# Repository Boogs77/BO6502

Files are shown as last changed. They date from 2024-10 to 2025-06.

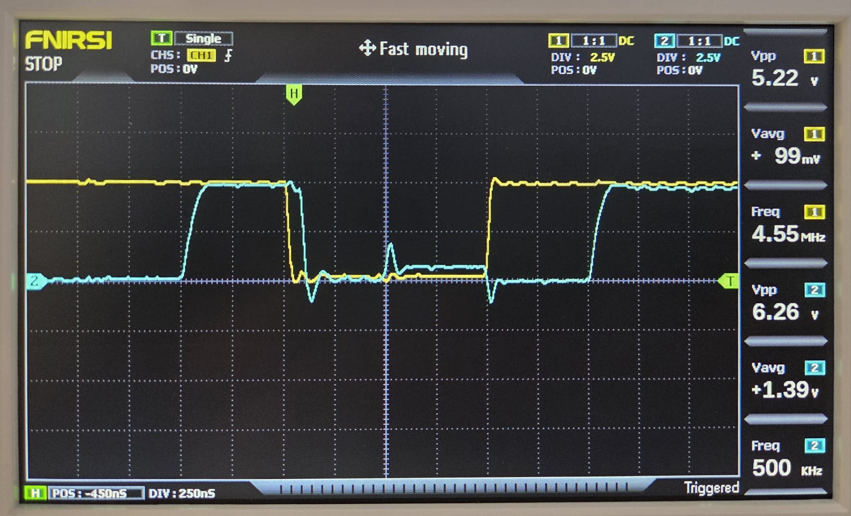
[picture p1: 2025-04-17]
BO6502 VDU/export/CSW-D7.jpg

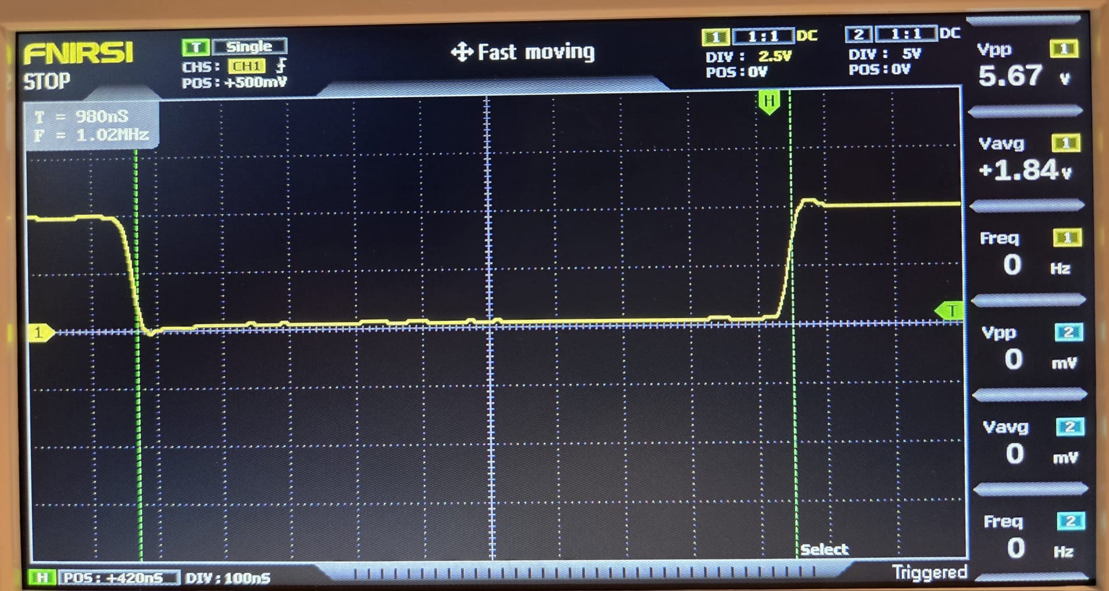
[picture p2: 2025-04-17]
BO6502 VDU/export/CSW.jpg

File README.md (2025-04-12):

**SPECIFICATION**

MICROPROCESSOR The Western Design Center Inc. W65C02S

Clock frequency 1.0 MHz

Optional Clock frequency 2.0 MHz e 500 KHz

ROM Memory ATMEL AT28C256

On-board ROM capacitor 32 Kbyte

RAM Memory HITACHI HM62256lp-12

On-board RAM capacitor 32 Kbyte

VIDEO OUTPUT LCD Display 16x2

Internal Chip HITACHI HD44780U

SERIAL COMMUNICATION Through serial port DB9

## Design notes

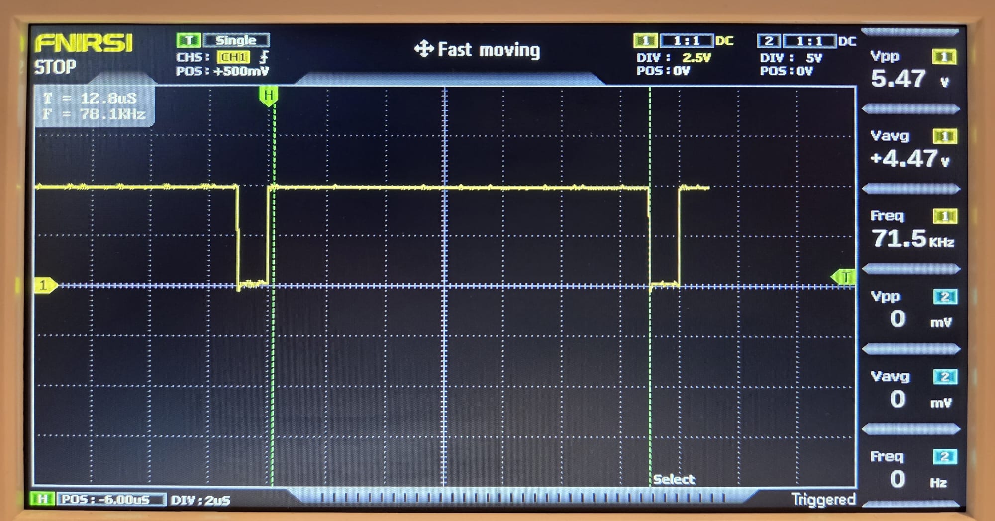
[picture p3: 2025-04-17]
BO6502 VDU/export/CSW-IN-LOOP.jpg

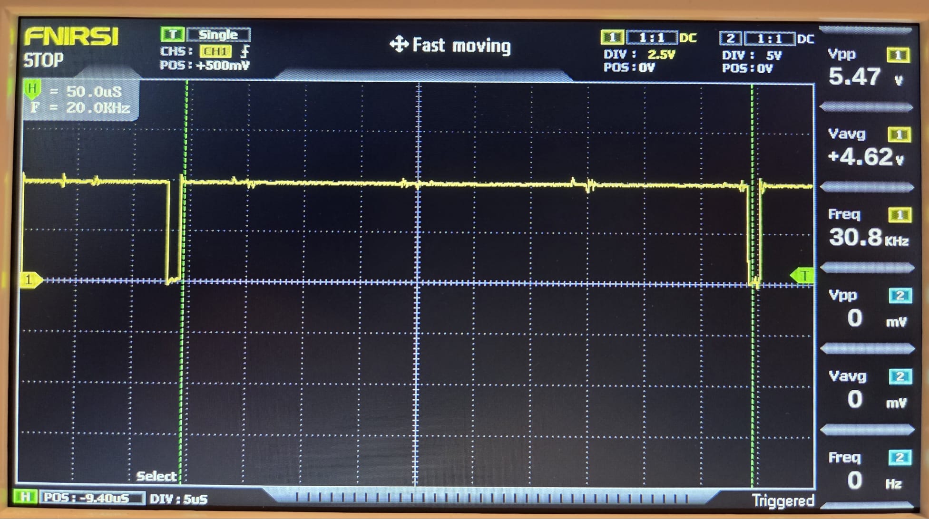
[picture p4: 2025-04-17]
BO6502 VDU/export/CSW-LOOP.jpg

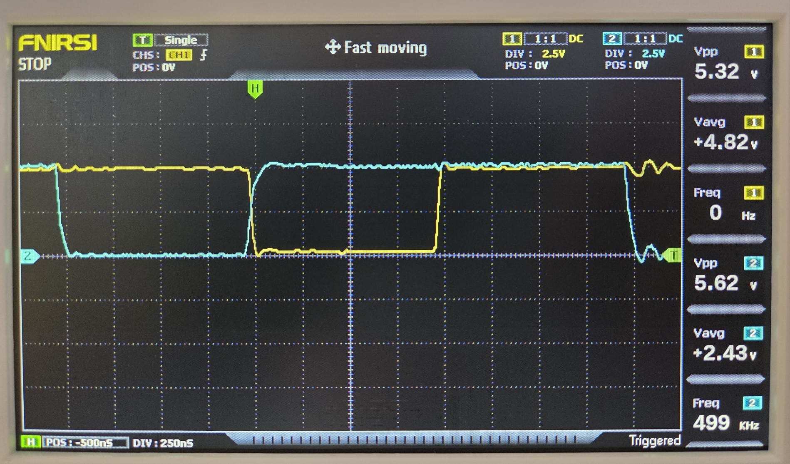
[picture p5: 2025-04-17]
BO6502 VDU/export/CSW-A0.jpg

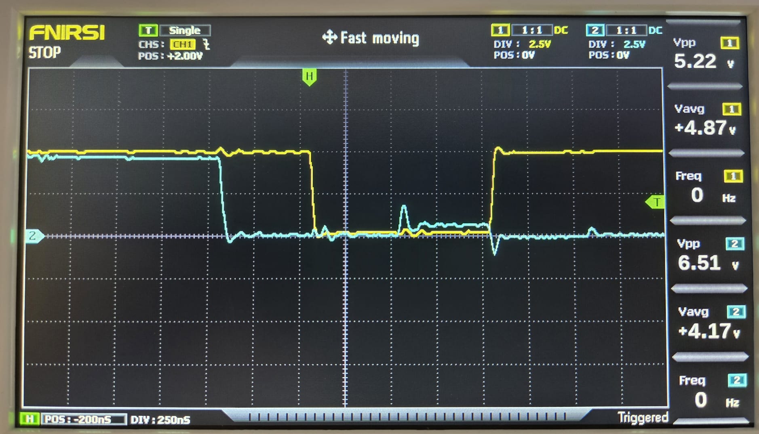
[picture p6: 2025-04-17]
BO6502 VDU/export/CSW-LSB.jpg

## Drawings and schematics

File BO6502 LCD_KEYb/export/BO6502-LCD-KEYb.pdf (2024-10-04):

A

A

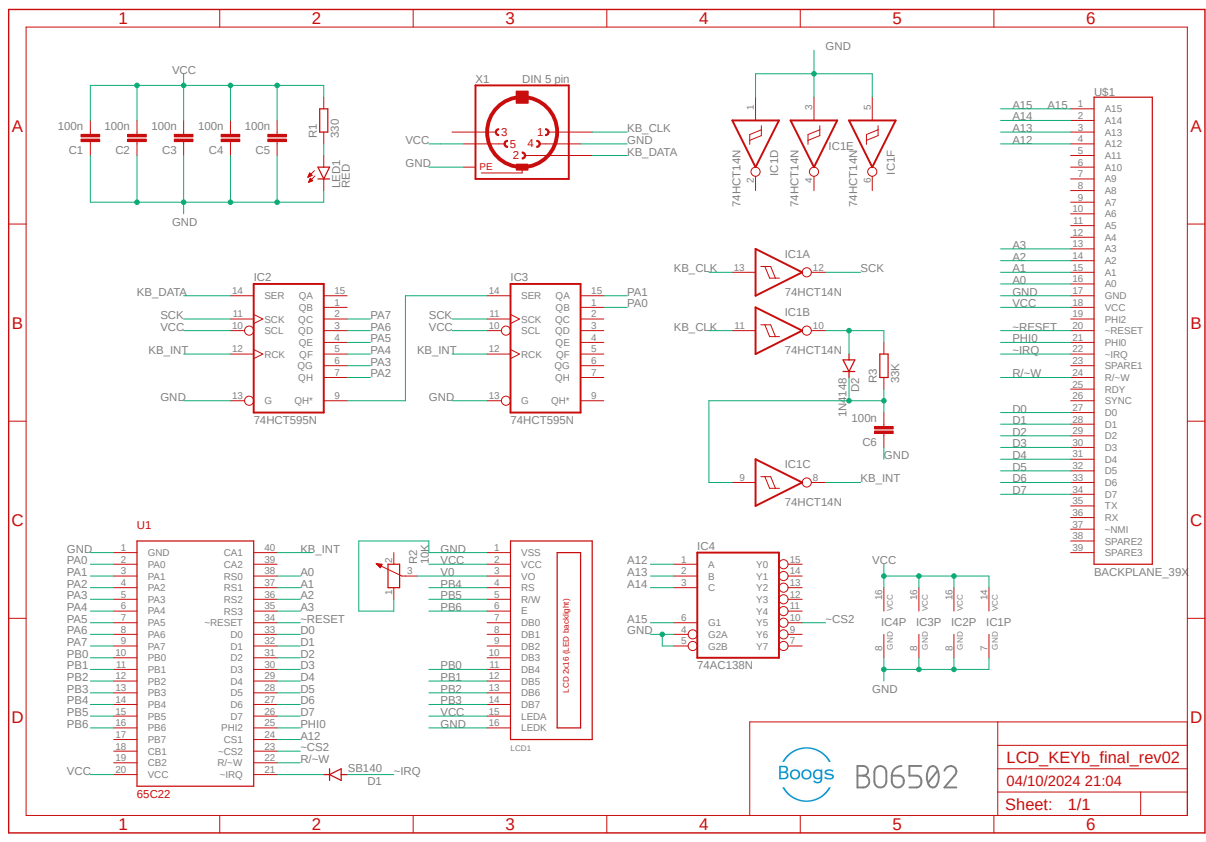
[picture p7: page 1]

GND

PB3 13 | | DB6 13
PB4 14 | DB7 14
PB5 15 | VCC | LEDA 15
PB6 16 | GND | LEDK 16

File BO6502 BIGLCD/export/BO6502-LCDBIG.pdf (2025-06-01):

Sheet: ABCD | 1 | 2 | 3 | 4 | 5 | 6 | ABCD 1 | 2 | 3 | 4 | 5 | 6

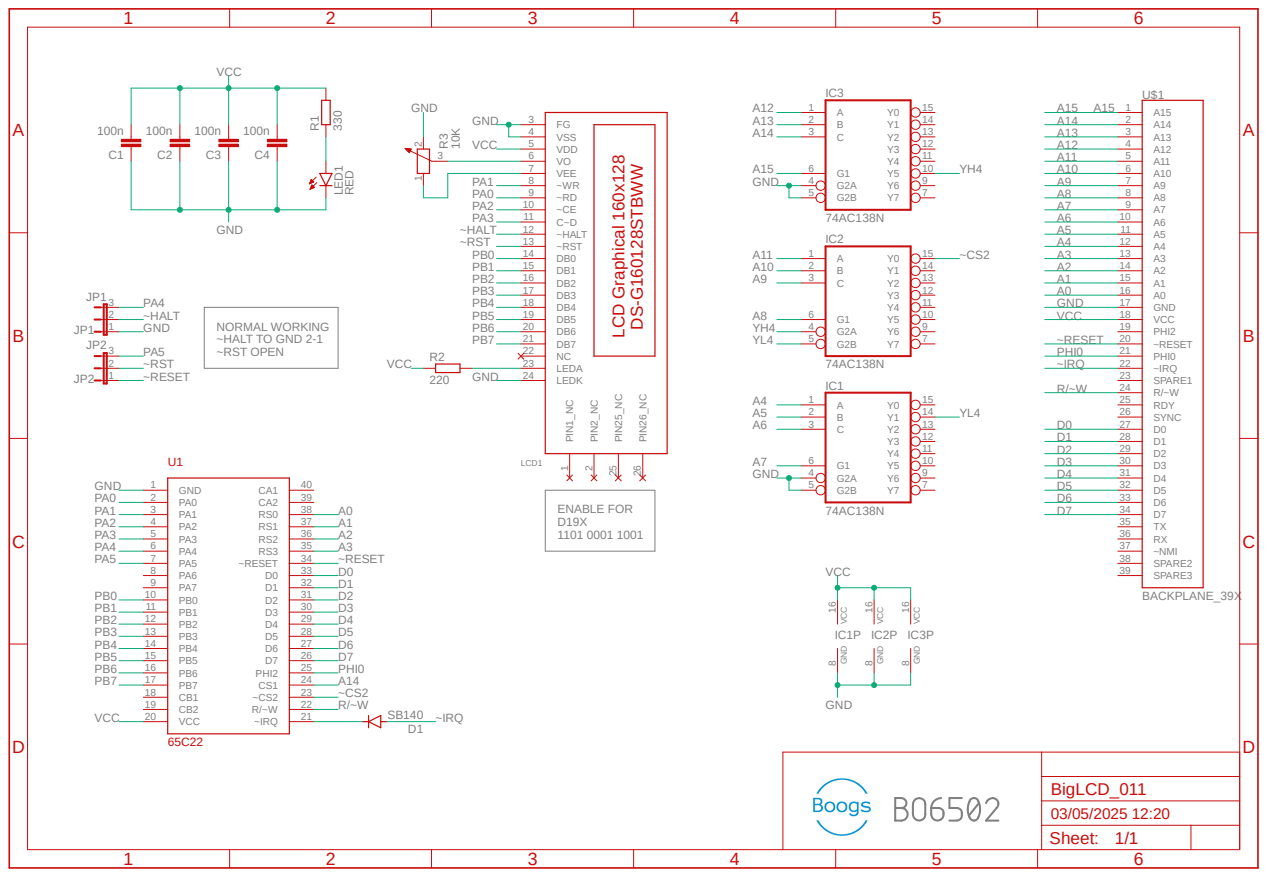
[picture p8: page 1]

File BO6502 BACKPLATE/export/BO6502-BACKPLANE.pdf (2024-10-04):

A

A

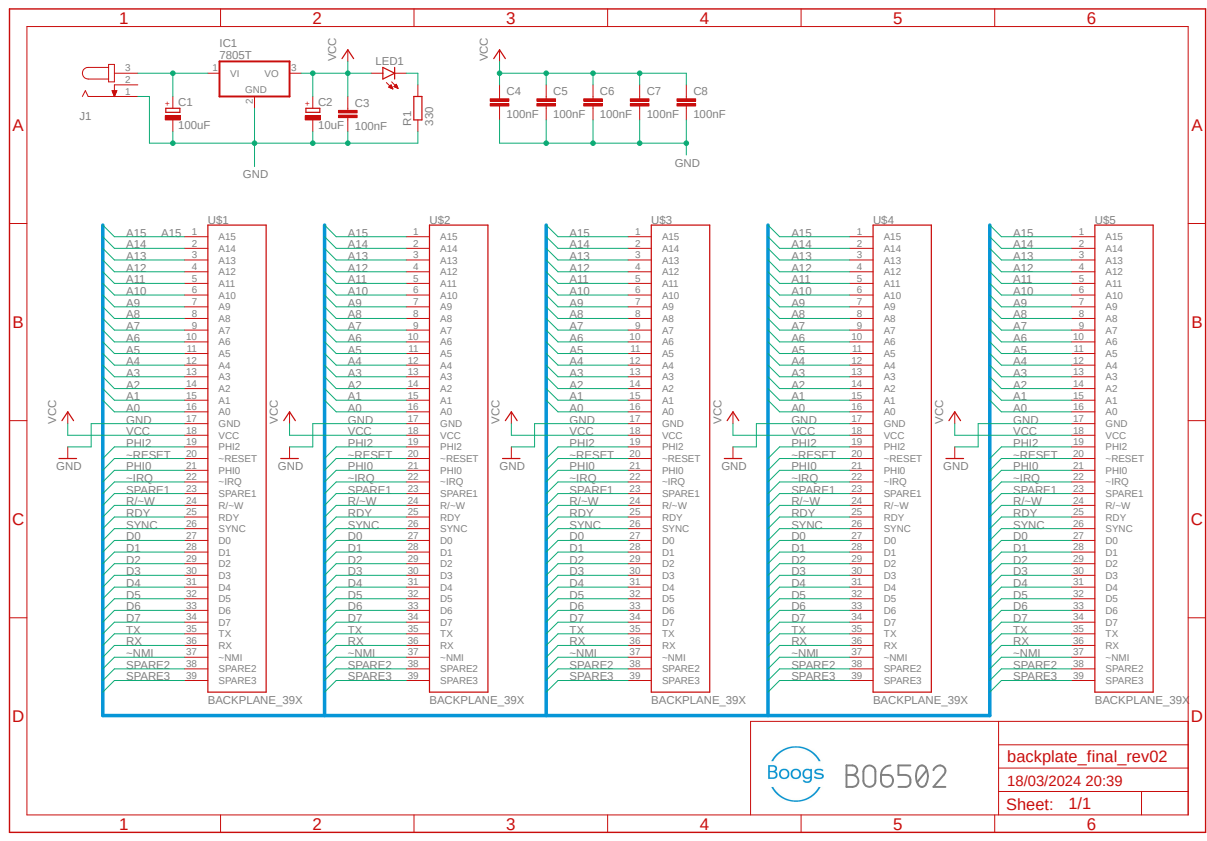
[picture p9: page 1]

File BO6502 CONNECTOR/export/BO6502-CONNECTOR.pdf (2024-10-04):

Sheet: ABCD | 1 | 2 | 3 | 4 | 5 | 6 | ABCD 1 | 2 | 3 | 4 | 5 | 6

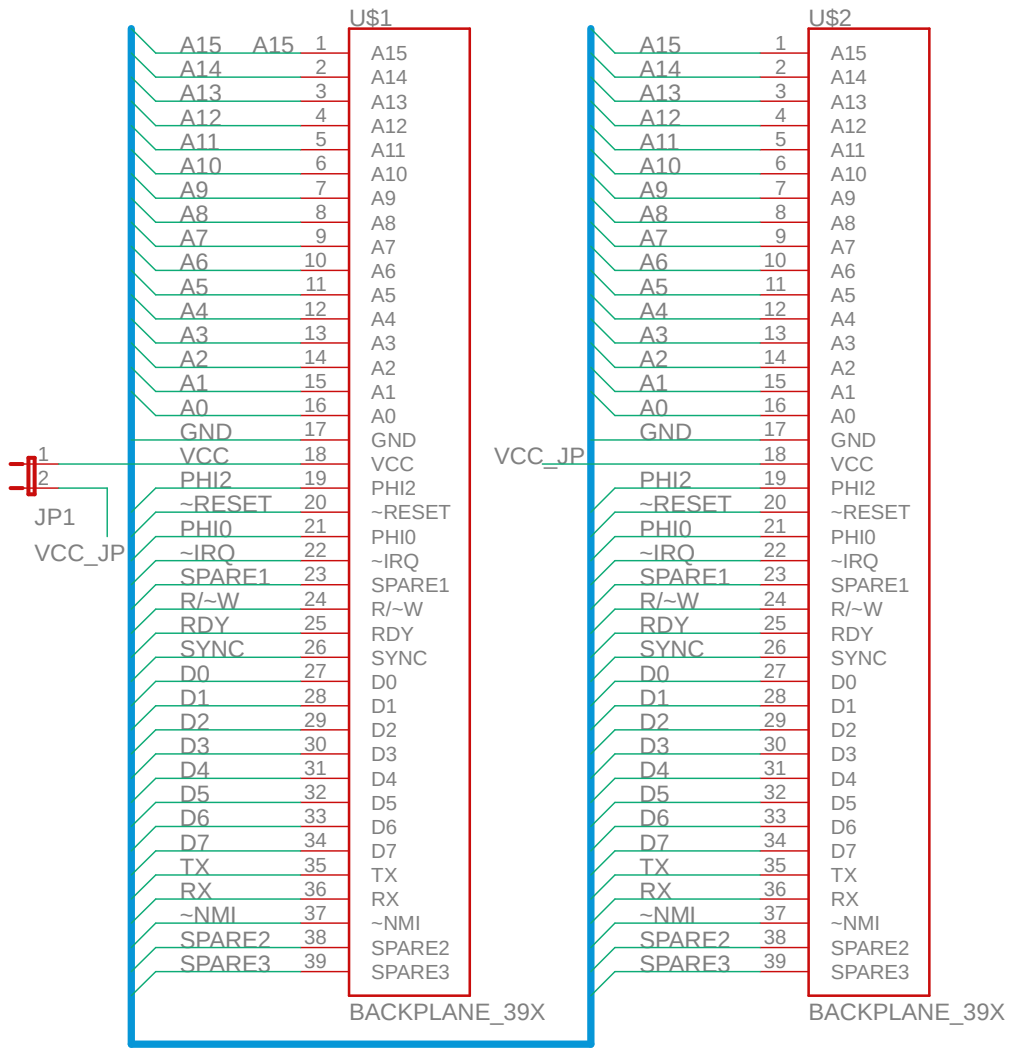
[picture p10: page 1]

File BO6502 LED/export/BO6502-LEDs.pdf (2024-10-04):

Y7 | 7 Y6 | 9 Y5 | 10 Y4 | 11 Y3 | 12 Y2 | 13 Y1 | 14 Y0 | 15
A

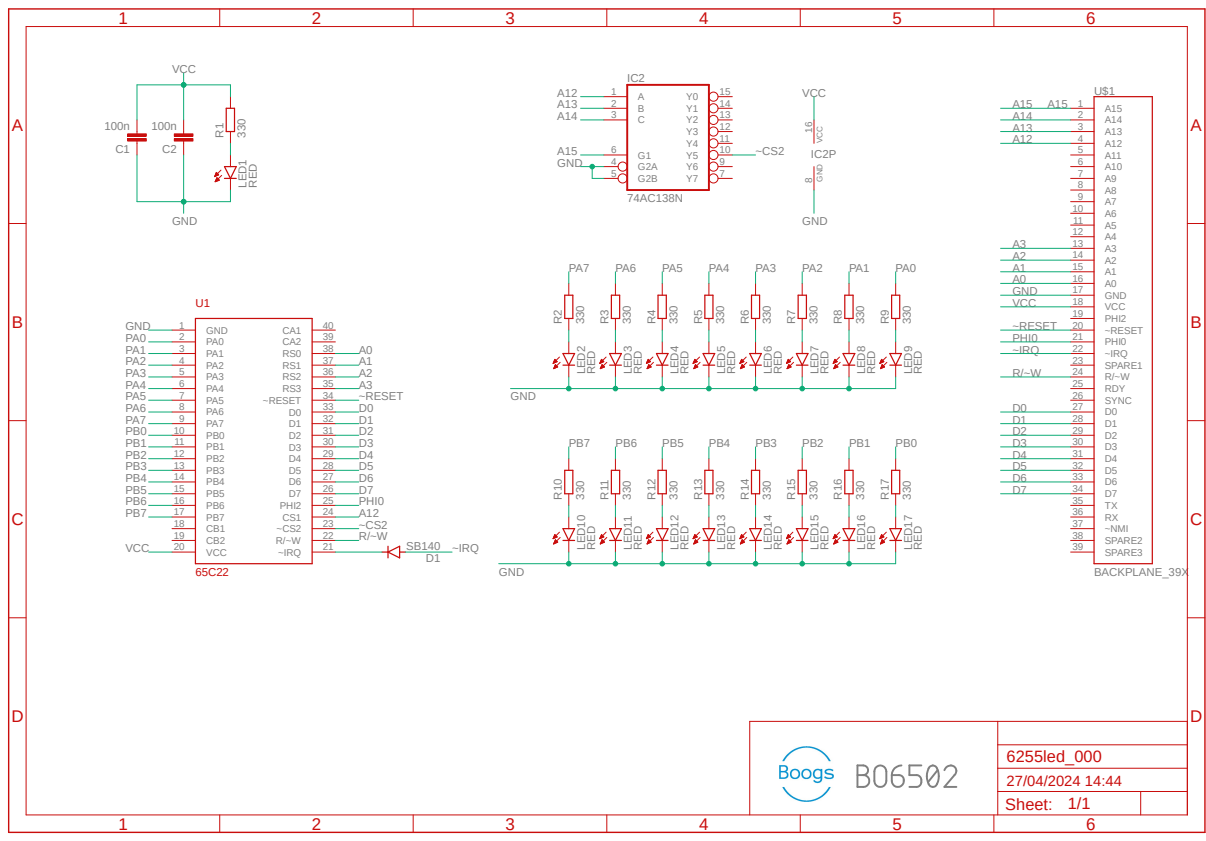
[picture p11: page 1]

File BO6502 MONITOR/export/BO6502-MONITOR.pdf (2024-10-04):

Sheet: ABCD | 1 | 2 | 3 | 4 | 5 | 6 | ABCD 1 | 2 | 3 | 4 | 5 | 6

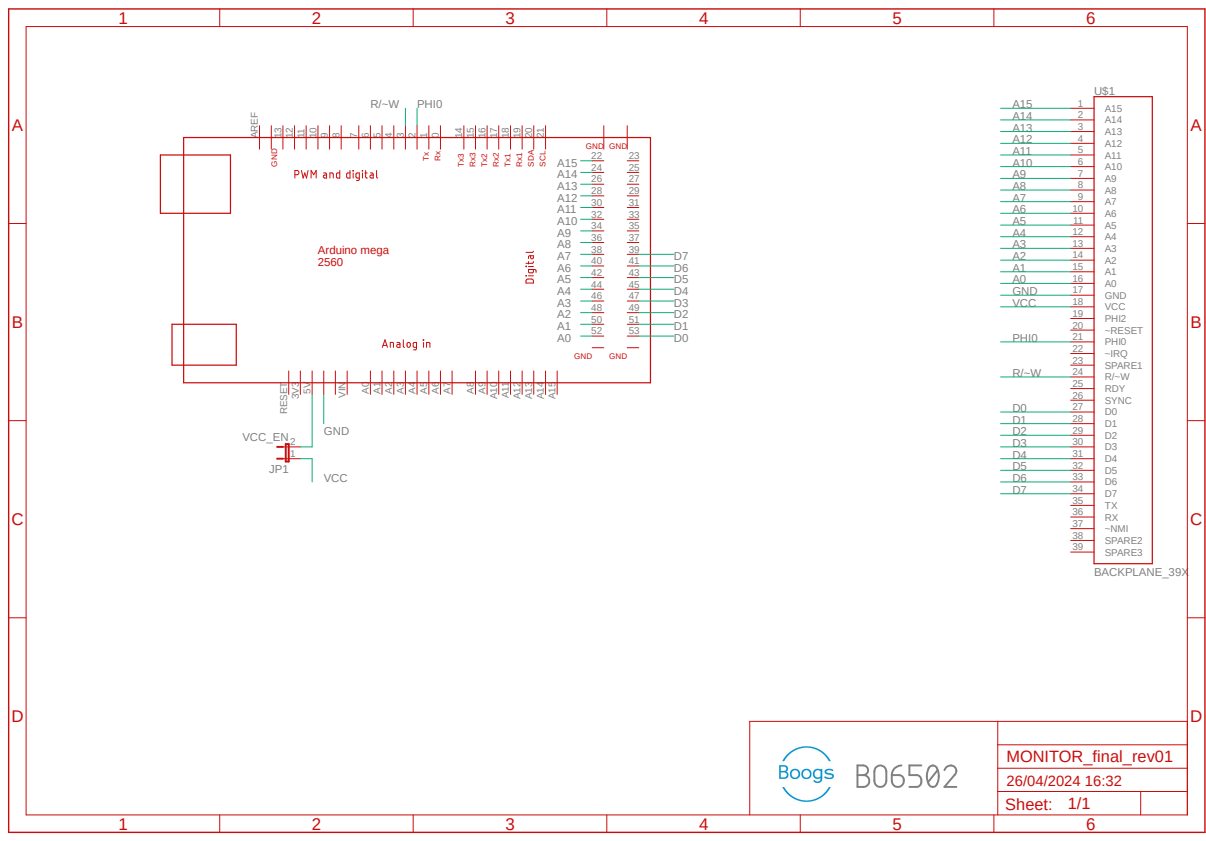
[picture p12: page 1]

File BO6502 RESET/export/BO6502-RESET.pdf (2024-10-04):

A

A

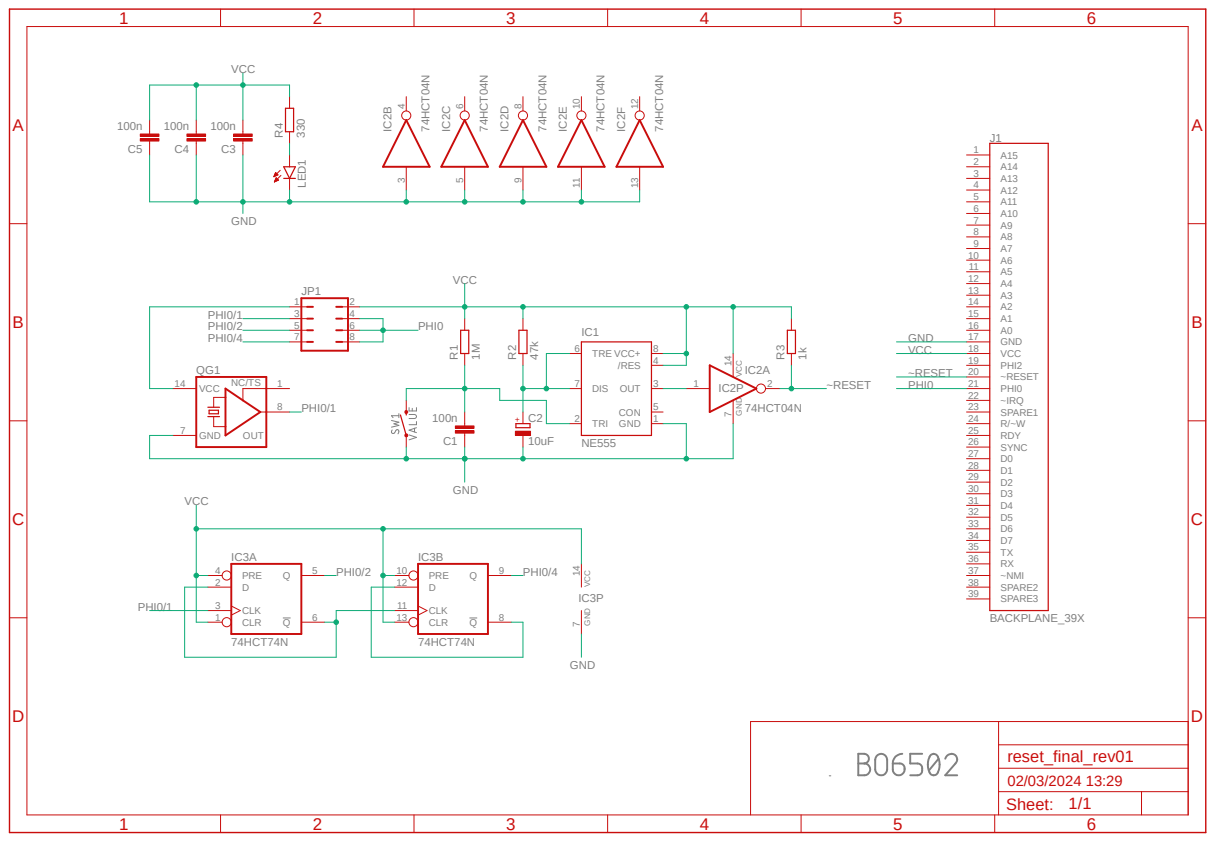
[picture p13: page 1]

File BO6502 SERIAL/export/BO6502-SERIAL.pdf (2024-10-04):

Sheet: ABCD | 1 | 2 | 3 | 4 | 5 | 6 | ABCD 1 | 2 | 3 | 4 | 5 | 6

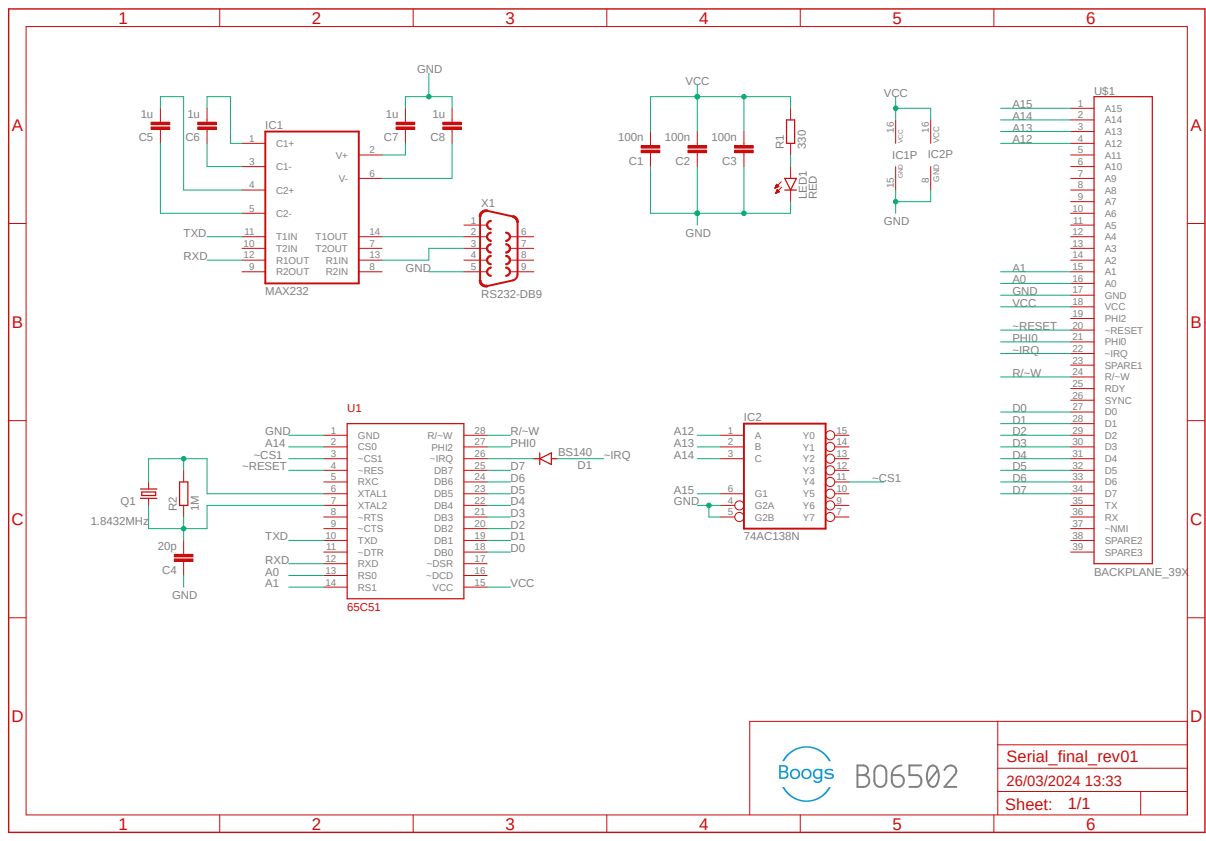
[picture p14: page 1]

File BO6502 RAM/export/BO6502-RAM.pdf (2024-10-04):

A

A

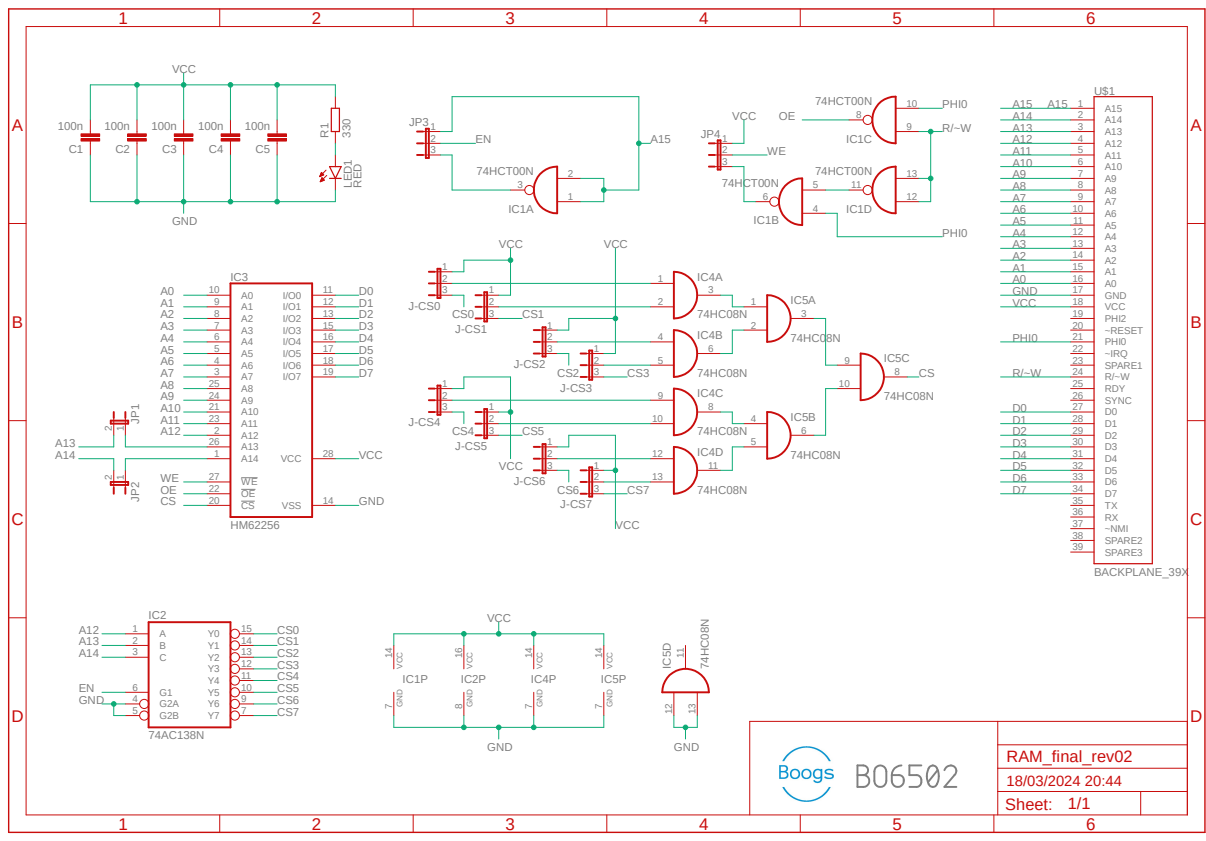
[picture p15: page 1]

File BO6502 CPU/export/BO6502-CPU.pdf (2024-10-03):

A

A

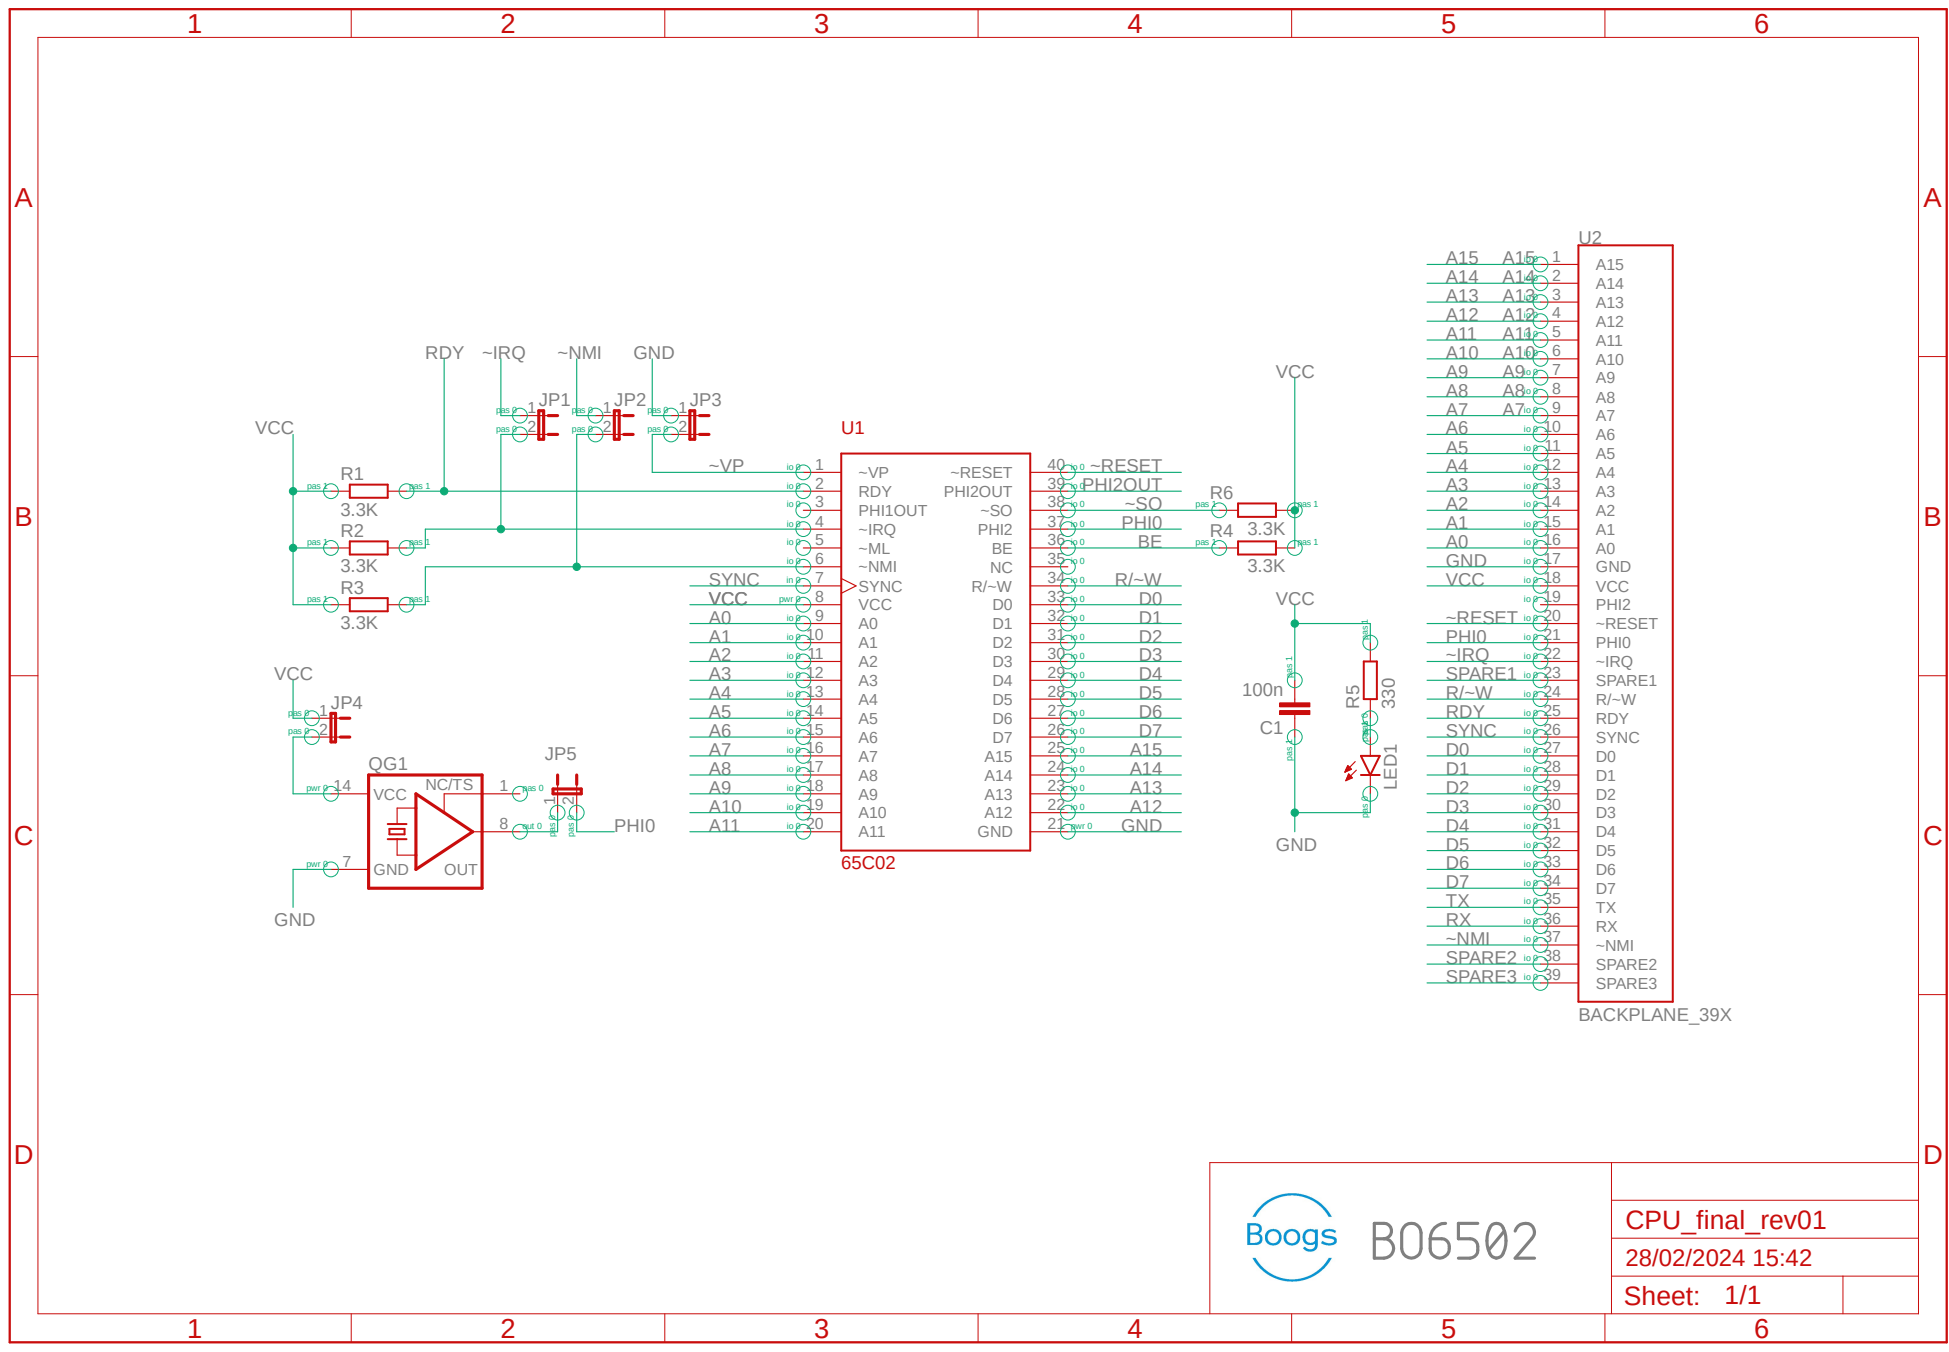
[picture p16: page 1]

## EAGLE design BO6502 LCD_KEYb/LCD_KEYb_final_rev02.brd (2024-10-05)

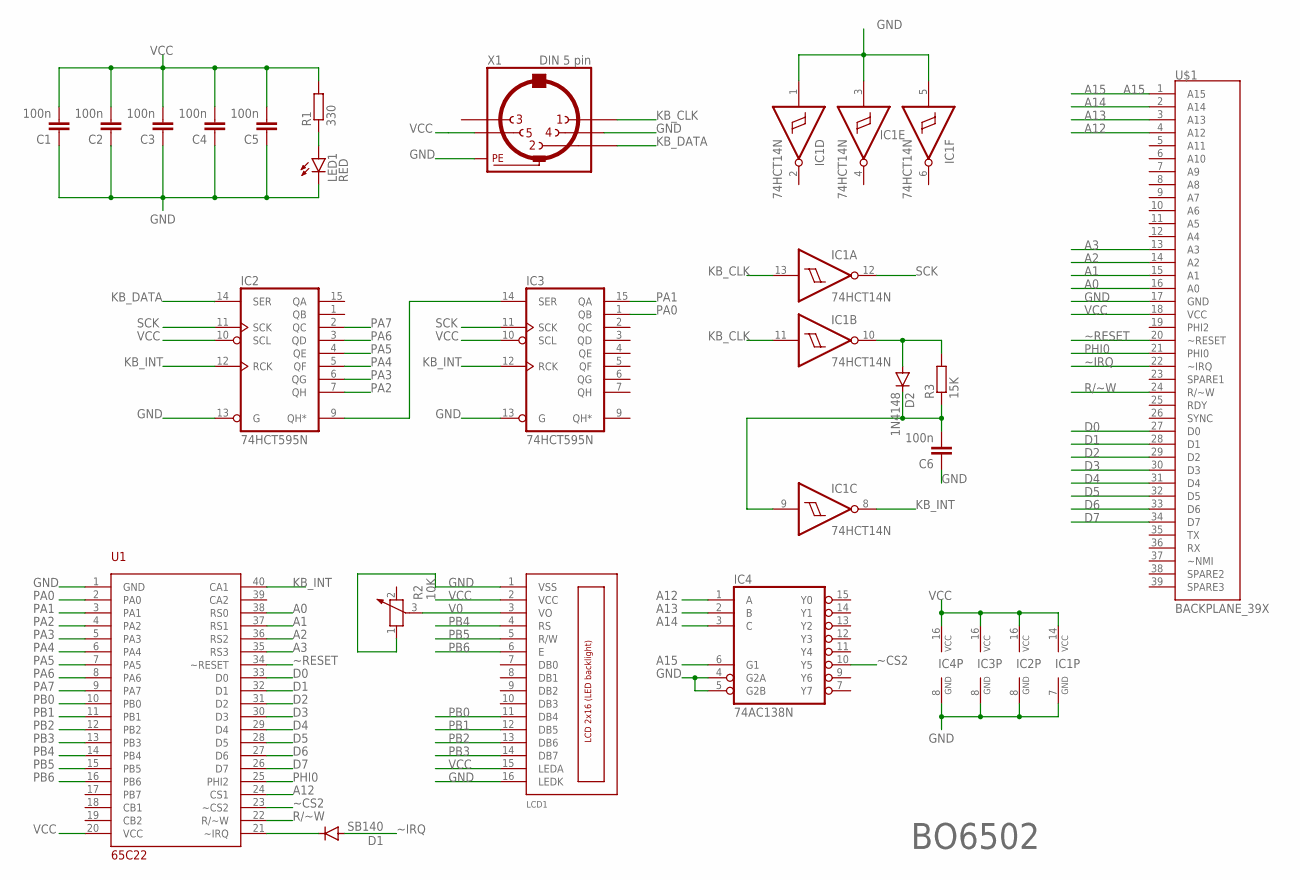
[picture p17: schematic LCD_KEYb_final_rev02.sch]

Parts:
C1, C2, C3, C4, C5, C6: 100n; C025-025X050
D1: SB140; DO41-10
D2: 1N4148; DO35-7
IC1: 74HCT14N; DIL14
IC2, IC3: 74HCT595N; DIL16
IC4: 74AC138N; DIL16
LCD1: LCD_2X16_SIL; HY-1602F
LED1: RED; LED5MM
R1: 330; 0207/10
R2: 10K; PT-10
R3: 15K; 0207/10
U1: 65C22; DIL40
U$1: BACKPLANE_39X; BP_39X
X1: DIN 5 pin; MAB5SH

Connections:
A0: U1.38 (RS0), U$1.16 (A0)
A1: U1.37 (RS1), U$1.15 (A1)
A2: U1.36 (RS2), U$1.14 (A2)
A3: U1.35 (RS3), U$1.13 (A3)
A12: IC4.1 (A), U1.24 (CS1), U$1.4 (A12)
A13: IC4.2 (B), U$1.3 (A13)
A14: IC4.3 (C), U$1.2 (A14)
A15: IC4.6 (G1), U$1.1 (A15)
D0: U1.33 (D0), U$1.27 (D0)
D1: U1.32 (D1), U$1.28 (D1)
D2: U1.31 (D2), U$1.29 (D2)
D3: U1.30 (D3), U$1.30 (D3)
D4: U1.29 (D4), U$1.31 (D4)
D5: U1.28 (D5), U$1.32 (D5)
D6: U1.27 (D6), U$1.33 (D6)
D7: U1.26 (D7), U$1.34 (D7)
GND: C1.1, C2.1, C3.1, C4.1, C5.1, C6.1, IC1.1 (I), IC1.3 (I), IC1.5 (I), IC1.7 (GND), IC2.8 (GND), IC2.13 (G), IC3.8 (GND), IC3.13 (G), IC4.4 (G2A), IC4.5 (G2B), IC4.8 (GND), LCD1.1 (VSS), LCD1.16 (LEDK), LED1.K (C), R2.1, U1.1 (GND), U$1.17 (GND), X1.4, X1.PE, X1.PE@ (PE)
KB_CLK: IC1.11 (I), IC1.13 (I), X1.1
KB_DATA: IC2.14 (SER), X1.2
KB_INT: IC1.8 (O), IC2.12 (RCK), IC3.12 (RCK), U1.40 (CA1)
unnamed: D1.C, U1.21 (~IRQ)
unnamed: IC2.9 (QH*), IC3.14 (SER)
unnamed: D2.A, IC1.10 (O), R3.2
unnamed: C6.2, D2.C, IC1.9 (I), R3.1
unnamed: LED1.A, R1.1
PA0: IC3.1 (QB), U1.2 (PA0)
PA1: IC3.15 (QA), U1.3 (PA1)
PA2: IC2.7 (QH), U1.4 (PA2)
PA3: IC2.6 (QG), U1.5 (PA3)
PA4: IC2.5 (QF), U1.6 (PA4)
PA5: IC2.4 (QE), U1.7 (PA5)
PA6: IC2.3 (QD), U1.8 (PA6)
PA7: IC2.2 (QC), U1.9 (PA7)
PB0: LCD1.11 (DB4), U1.10 (PB0)
PB1: LCD1.12 (DB5), U1.11 (PB1)
PB2: LCD1.13 (DB6), U1.12 (PB2)
PB3: LCD1.14 (DB7), U1.13 (PB3)
PB4: LCD1.4 (RS), U1.14 (PB4)
PB5: LCD1.5 (R/W), U1.15 (PB5)
PB6: LCD1.6 (E), U1.16 (PB6)
PHI0: U1.25 (PHI2), U$1.21 (PHI0)
R/~W: U1.22 (R/~W), U$1.24 (R/~W)
SCK: IC1.12 (O), IC2.11 (SCK), IC3.11 (SCK)
V0: LCD1.3 (VO), R2.3
VCC: C1.2, C2.2, C3.2, C4.2, C5.2, IC1.14 (VCC), IC2.10 (SCL), IC2.16 (VCC), IC3.10 (SCL), IC3.16 (VCC), IC4.16 (VCC), LCD1.2 (VCC), LCD1.15 (LEDA), R1.2, U1.20 (VCC), U$1.18 (VCC), X1.5
~CS2: IC4.10 (Y5), U1.23 (~CS2)
~IRQ: D1.A, U$1.22 (~IRQ)
~RESET: U1.34 (~RESET), U$1.20 (~RESET)

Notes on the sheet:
BO6502

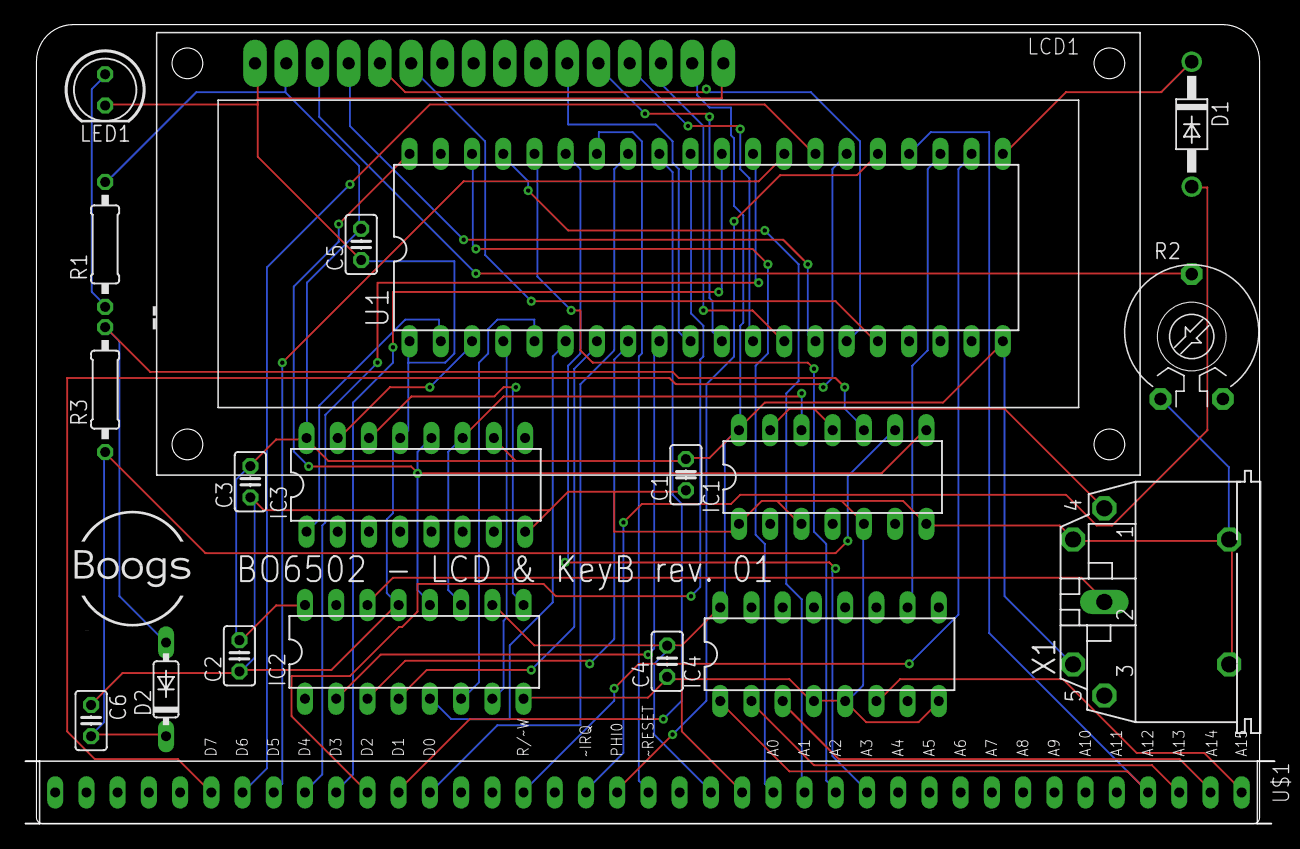
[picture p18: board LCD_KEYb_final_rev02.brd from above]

Board: 2 copper layers, 101.6 x 65.0 mm, 20 parts (0 on the bottom side), 48 nets.

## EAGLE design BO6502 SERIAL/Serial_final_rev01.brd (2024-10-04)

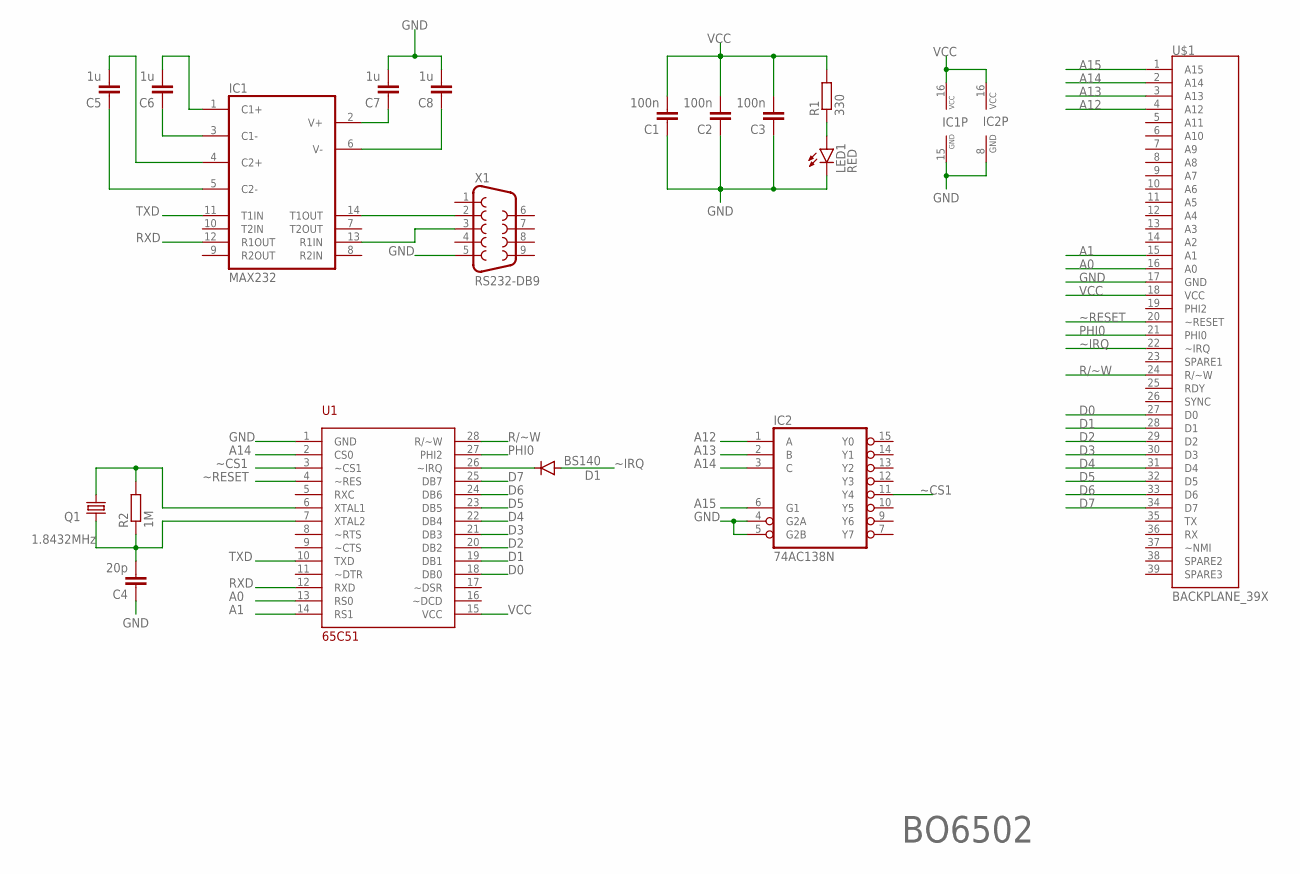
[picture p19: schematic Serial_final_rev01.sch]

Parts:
C1, C2, C3: 100n; C025-025X050
C4: 20p; C025-025X050
C5, C6, C7, C8: 1u; C050-025X075
D1: BS140; DO41-10
IC1: MAX232; DIL16
IC2: 74AC138N; DIL16
LED1: RED; LED5MM
Q1: 1.8432MHz; HC49/S
R1: 330; 0207/10
R2: 1M; 0207/10
U1: 65C51; DIL28
U$1: BACKPLANE_39X; BP_39X
X1: RS232-DB9; F09HP

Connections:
A0: U1.13 (RS0), U$1.16 (A0)
A1: U1.14 (RS1), U$1.15 (A1)
A12: IC2.1 (A), U$1.4 (A12)
A13: IC2.2 (B), U$1.3 (A13)
A14: IC2.3 (C), U1.2 (CS0), U$1.2 (A14)
A15: IC2.6 (G1), U$1.1 (A15)
D0: U1.18 (DB0), U$1.27 (D0)
D1: U1.19 (DB1), U$1.28 (D1)
D2: U1.20 (DB2), U$1.29 (D2)
D3: U1.21 (DB3), U$1.30 (D3)
D4: U1.22 (DB4), U$1.31 (D4)
D5: U1.23 (DB5), U$1.32 (D5)
D6: U1.24 (DB6), U$1.33 (D6)
D7: U1.25 (DB7), U$1.34 (D7)
GND: C1.1, C2.1, C3.1, C4.1, C7.2, C8.2, IC1.15 (GND), IC2.4 (G2A), IC2.5 (G2B), IC2.8 (GND), LED1.K (C), U1.1 (GND), U$1.17 (GND), X1.5
unnamed: C6.2, IC1.1 (C1+)
unnamed: D1.C, U1.26 (~IRQ)
unnamed: C6.1, IC1.3 (C1-)
unnamed: C5.2, IC1.4 (C2+)
unnamed: C5.1, IC1.5 (C2-)
unnamed: LED1.A, R1.1
unnamed: IC1.14 (T1OUT), X1.2
unnamed: IC1.13 (R1IN), X1.3
unnamed: C7.1, IC1.2 (V+)
unnamed: C8.1, IC1.6 (V-)
unnamed: Q1.2, R2.2, U1.6 (XTAL1)
unnamed: C4.2, Q1.1, R2.1, U1.7 (XTAL2)
PHI0: U1.27 (PHI2), U$1.21 (PHI0)
R/~W: U1.28 (R/~W), U$1.24 (R/~W)
RXD: IC1.12 (R1OUT), U1.12 (RXD)
TXD: IC1.11 (T1IN), U1.10 (TXD)
VCC: C1.2, C2.2, C3.2, IC1.16 (VCC), IC2.16 (VCC), R1.2, U1.15 (VCC), U$1.18 (VCC)
~CS1: IC2.11 (Y4), U1.3 (~CS1)
~IRQ: D1.A, U$1.22 (~IRQ)
~RESET: U1.4 (~RES), U$1.20 (~RESET)

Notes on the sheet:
BO6502

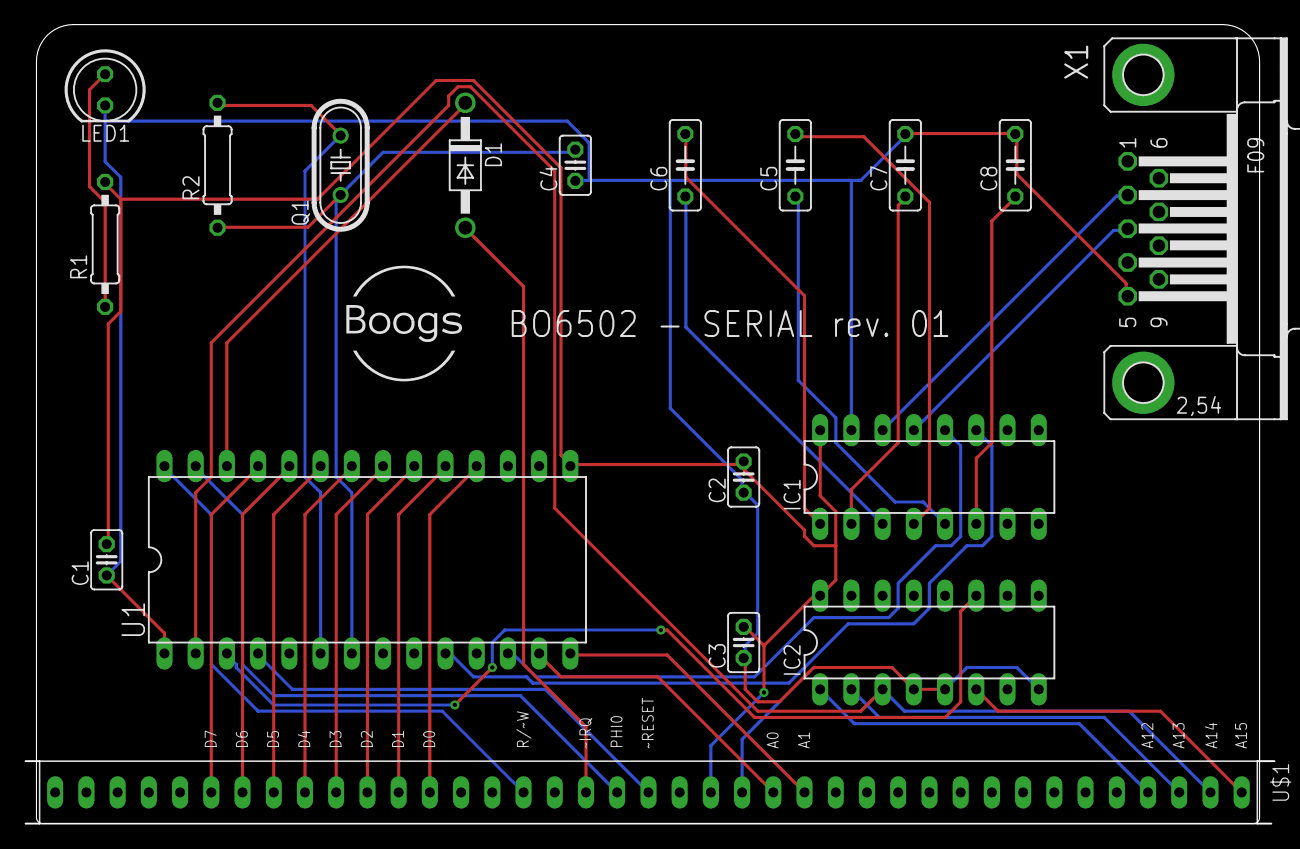
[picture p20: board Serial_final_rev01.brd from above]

Board: 2 copper layers, 101.6 x 65.0 mm, 18 parts (0 on the bottom side), 35 nets.

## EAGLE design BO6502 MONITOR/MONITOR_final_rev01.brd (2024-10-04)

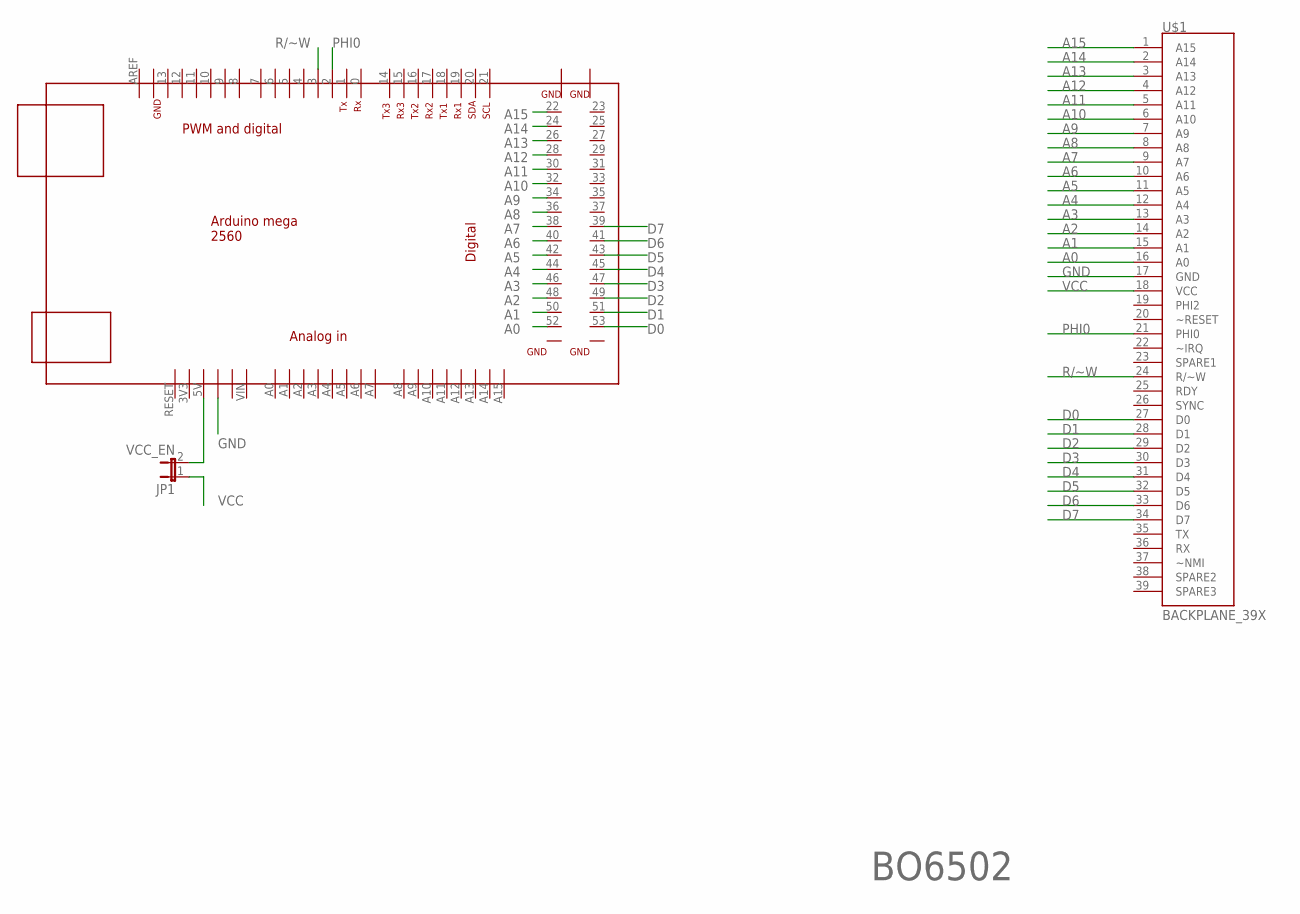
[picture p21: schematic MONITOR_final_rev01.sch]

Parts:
JP1: VCC_EN; JP1
U$1: BACKPLANE_39X; BP_39X
U$2: MEGA_DEVICE; MEGAOUTLINE

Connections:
A0: U$1.16 (A0), U$2.52
A1: U$1.15 (A1), U$2.50
A2: U$1.14 (A2), U$2.48
A3: U$1.13 (A3), U$2.46
A4: U$1.12 (A4), U$2.44
A5: U$1.11 (A5), U$2.42
A6: U$1.10 (A6), U$2.40
A7: U$1.9 (A7), U$2.38
A8: U$1.8 (A8), U$2.36
A9: U$1.7 (A9), U$2.34
A10: U$1.6 (A10), U$2.32
A11: U$1.5 (A11), U$2.30
A12: U$1.4 (A12), U$2.28
A13: U$1.3 (A13), U$2.26
A14: U$1.2 (A14), U$2.24
A15: U$1.1 (A15), U$2.22
D0: U$1.27 (D0), U$2.53
D1: U$1.28 (D1), U$2.51
D2: U$1.29 (D2), U$2.49
D3: U$1.30 (D3), U$2.47
D4: U$1.31 (D4), U$2.45
D5: U$1.32 (D5), U$2.43
D6: U$1.33 (D6), U$2.41
D7: U$1.34 (D7), U$2.39
GND: U$1.17 (GND), U$2.GND@2 (GND)
unnamed: JP1.2, U$2.5V
PHI0: U$1.21 (PHI0), U$2.2
R/~W: U$1.24 (R/~W), U$2.3
VCC: JP1.1, U$1.18 (VCC)

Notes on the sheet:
BO6502

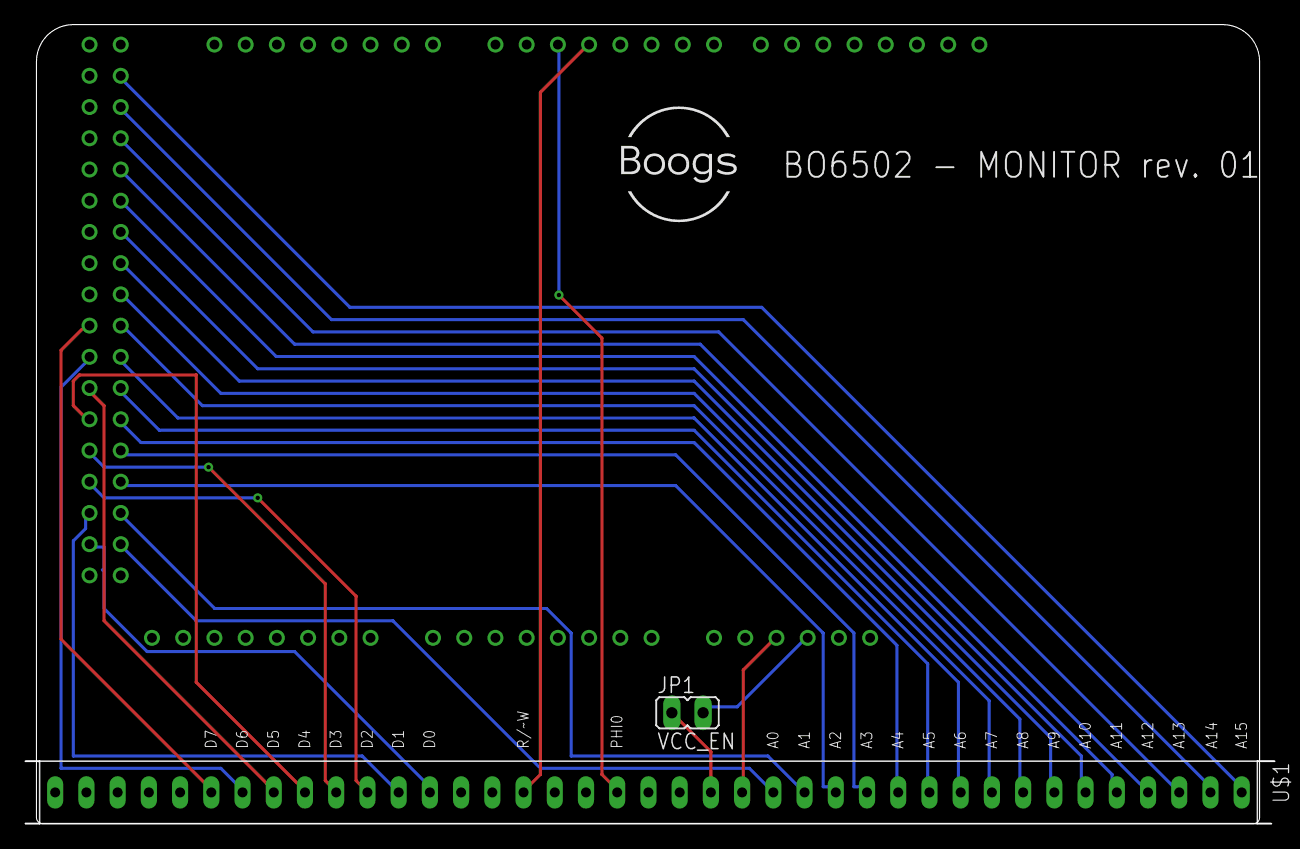
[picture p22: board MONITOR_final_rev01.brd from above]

Board: 2 copper layers, 101.6 x 65.0 mm, 3 parts (1 on the bottom side), 29 nets.

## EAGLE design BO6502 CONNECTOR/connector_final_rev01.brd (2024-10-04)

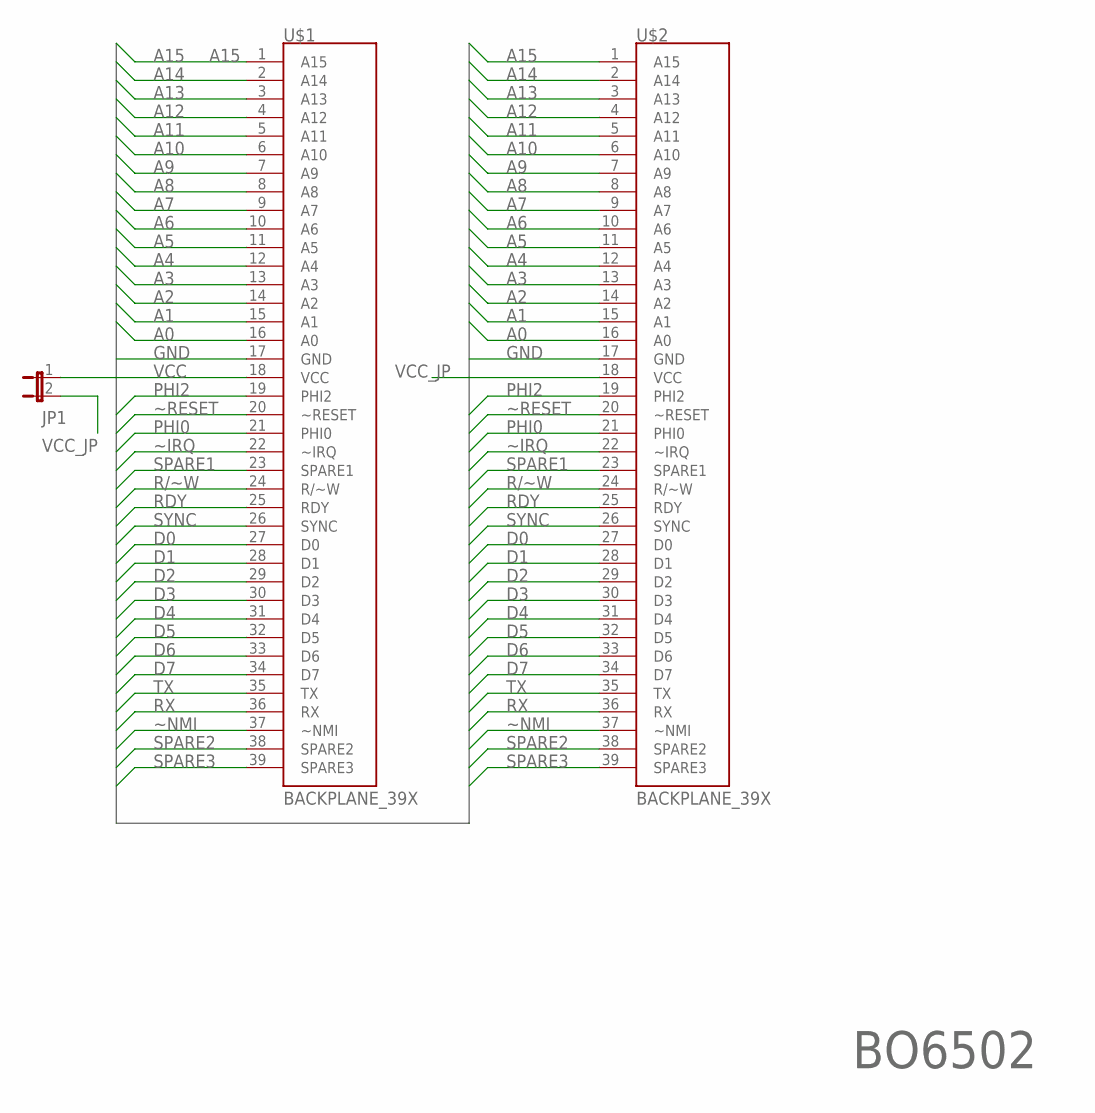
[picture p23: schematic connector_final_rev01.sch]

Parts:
JP1: JP1E; JP1
U$1, U$2: BACKPLANE_39X; BP_39X

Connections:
A0: U$1.16 (A0), U$2.16 (A0)
A1: U$1.15 (A1), U$2.15 (A1)
A2: U$1.14 (A2), U$2.14 (A2)
A3: U$1.13 (A3), U$2.13 (A3)
A4: U$1.12 (A4), U$2.12 (A4)
A5: U$1.11 (A5), U$2.11 (A5)
A6: U$1.10 (A6), U$2.10 (A6)
A7: U$1.9 (A7), U$2.9 (A7)
A8: U$1.8 (A8), U$2.8 (A8)
A9: U$1.7 (A9), U$2.7 (A9)
A10: U$1.6 (A10), U$2.6 (A10)
A11: U$1.5 (A11), U$2.5 (A11)
A12: U$1.4 (A12), U$2.4 (A12)
A13: U$1.3 (A13), U$2.3 (A13)
A14: U$1.2 (A14), U$2.2 (A14)
A15: U$1.1 (A15), U$2.1 (A15)
D0: U$1.27 (D0), U$2.27 (D0)
D1: U$1.28 (D1), U$2.28 (D1)
D2: U$1.29 (D2), U$2.29 (D2)
D3: U$1.30 (D3), U$2.30 (D3)
D4: U$1.31 (D4), U$2.31 (D4)
D5: U$1.32 (D5), U$2.32 (D5)
D6: U$1.33 (D6), U$2.33 (D6)
D7: U$1.34 (D7), U$2.34 (D7)
GND: U$1.17 (GND), U$2.17 (GND)
PHI0: U$1.21 (PHI0), U$2.21 (PHI0)
PHI2: U$1.19 (PHI2), U$2.19 (PHI2)
R/~W: U$1.24 (R/~W), U$2.24 (R/~W)
RDY: U$1.25 (RDY), U$2.25 (RDY)
RX: U$1.36 (RX), U$2.36 (RX)
SPARE1: U$1.23 (SPARE1), U$2.23 (SPARE1)
SPARE2: U$1.38 (SPARE2), U$2.38 (SPARE2)
SPARE3: U$1.39 (SPARE3), U$2.39 (SPARE3)
SYNC: U$1.26 (SYNC), U$2.26 (SYNC)
TX: U$1.35 (TX), U$2.35 (TX)
VCC: JP1.1, U$1.18 (VCC)
VCC_JP: JP1.2, U$2.18 (VCC)
~IRQ: U$1.22 (~IRQ), U$2.22 (~IRQ)
~NMI: U$1.37 (~NMI), U$2.37 (~NMI)
~RESET: U$1.20 (~RESET), U$2.20 (~RESET)

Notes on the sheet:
BO6502

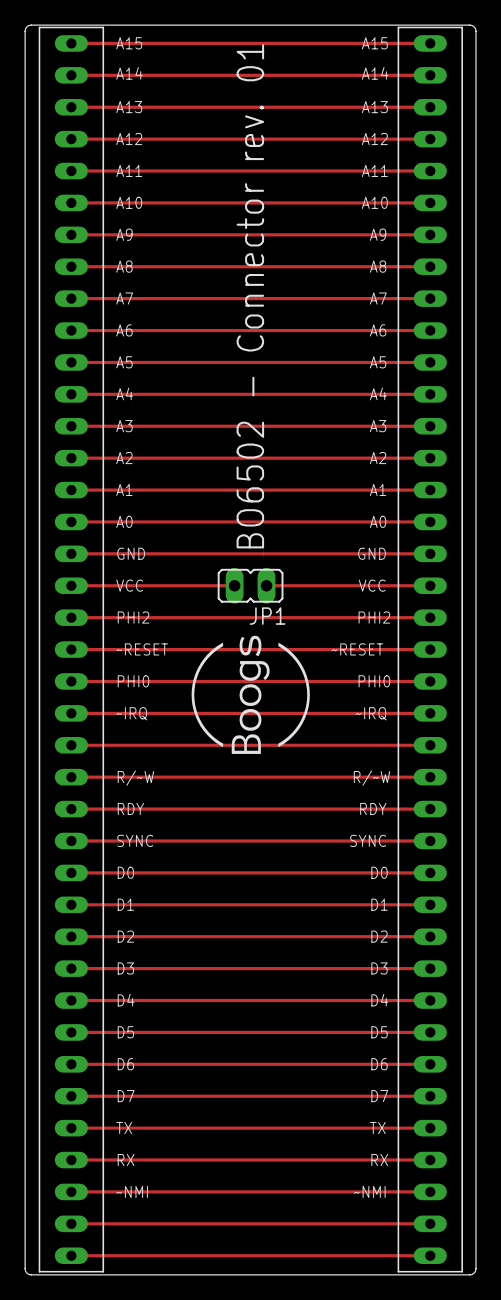
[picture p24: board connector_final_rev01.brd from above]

Board: 2 copper layers, 35.9 x 99.5 mm, 3 parts (0 on the bottom side), 40 nets.

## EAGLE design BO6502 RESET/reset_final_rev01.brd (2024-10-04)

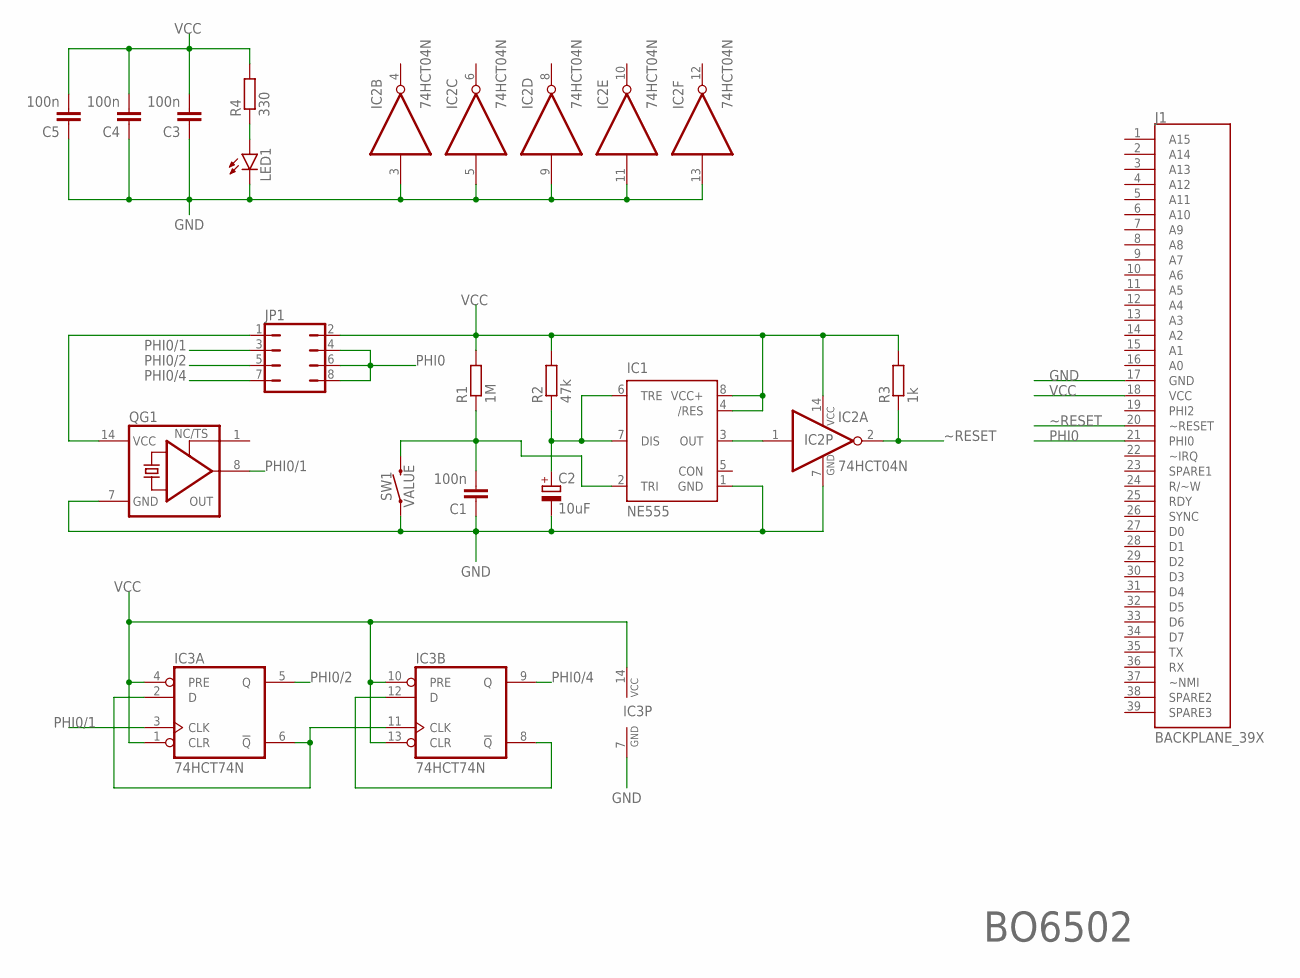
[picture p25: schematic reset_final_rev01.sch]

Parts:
C1, C3, C4, C5: 100n; C025-025X050
C2: 10uF; B45181A
IC1: NE555; DIL-08
IC2: 74HCT04N; DIL14
IC3: 74HCT74N; DIL14
J1: BACKPLANE_39X; BP_39X
JP1: JP4Q
LED1: LED5MM
QG1: XO-14; DIL14S
R1: 1M; 0207/10
R2: 47k; 0207/10
R3: 1k; 0207/10
R4: 330; 0207/10
SW1: MOMENTARY-SWITCH-SPST-PTH-6.0MM-KIT; TACTILE_SWITCH_PTH_6.0MM_KIT

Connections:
GND: C1.1, C2.-, C3.1, C4.1, C5.1, IC1.1 (GND), IC2.3 (I), IC2.5 (I), IC2.7 (GND), IC2.9 (I), IC2.11 (I), IC2.13 (I), IC3.7 (GND), J1.17 (GND), LED1.K (C), QG1.7 (GND), SW1.1
unnamed: JP1.1, QG1.14 (VCC)
unnamed: IC1.3 (OUT), IC2.1 (I)
unnamed: C2.+, IC1.6 (TRE), IC1.7 (DIS), R2.1
unnamed: C1.2, IC1.2 (TRI), R1.1, SW1.3 (2)
unnamed: LED1.A, R4.1
unnamed: IC3.2 (D), IC3.6 (!Q), IC3.11 (CLK)
unnamed: IC3.8 (!Q), IC3.12 (D)
PHI0: J1.21 (PHI0), JP1.4, JP1.6, JP1.8
PHI0/1: IC3.3 (CLK), JP1.3, QG1.8 (OUT)
PHI0/2: IC3.5 (Q), JP1.5
PHI0/4: IC3.9 (Q), JP1.7
VCC: C3.2, C4.2, C5.2, IC1.4 (/RES), IC1.8 (VCC+), IC2.14 (VCC), IC3.1 (CLR), IC3.4 (PRE), IC3.10 (PRE), IC3.13 (CLR), IC3.14 (VCC), J1.18 (VCC), JP1.2, R1.2, R2.2, R3.2, R4.2
~RESET: IC2.2 (O), J1.20 (~RESET), R3.1

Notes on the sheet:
BO6502

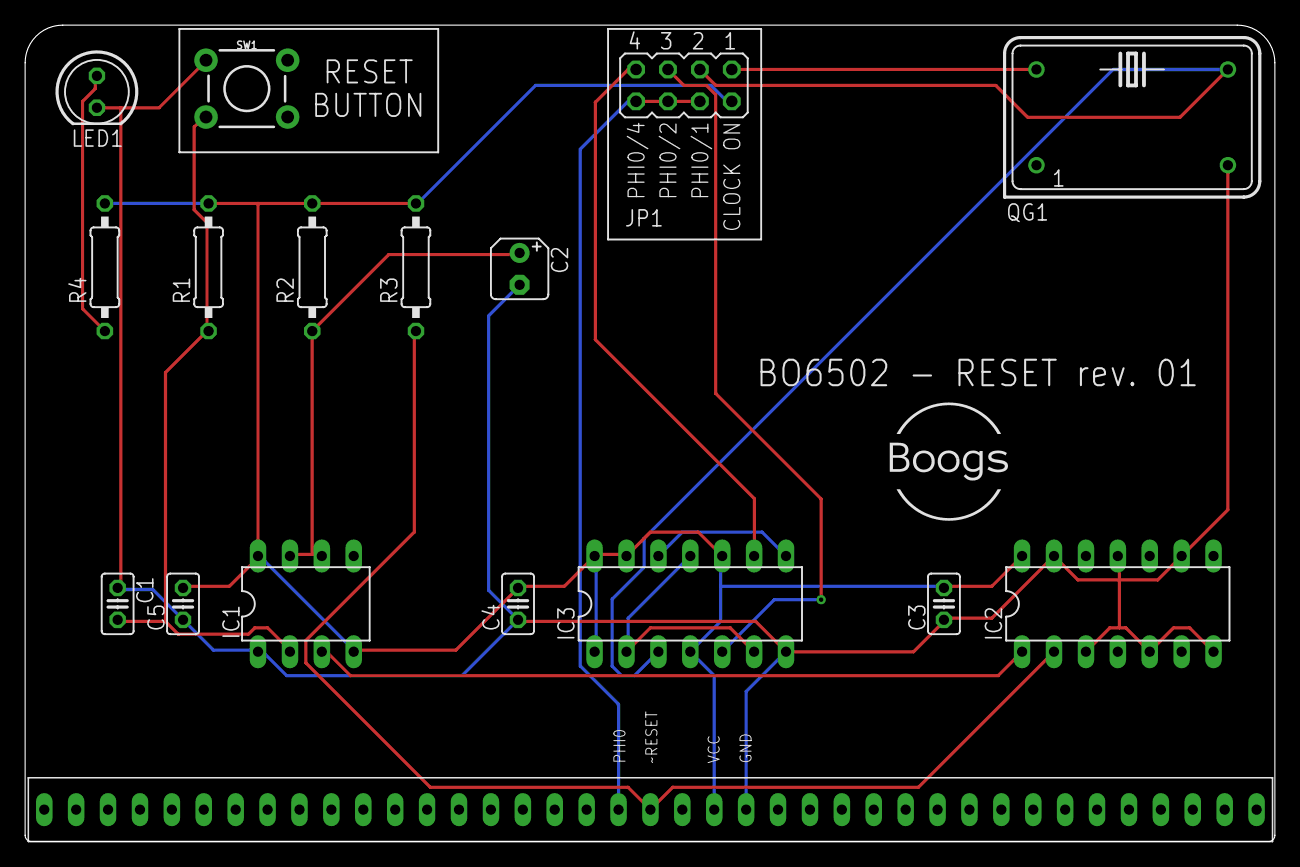
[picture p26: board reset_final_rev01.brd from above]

Board: 2 copper layers, 99.5 x 65.0 mm, 17 parts (0 on the bottom side), 14 nets.

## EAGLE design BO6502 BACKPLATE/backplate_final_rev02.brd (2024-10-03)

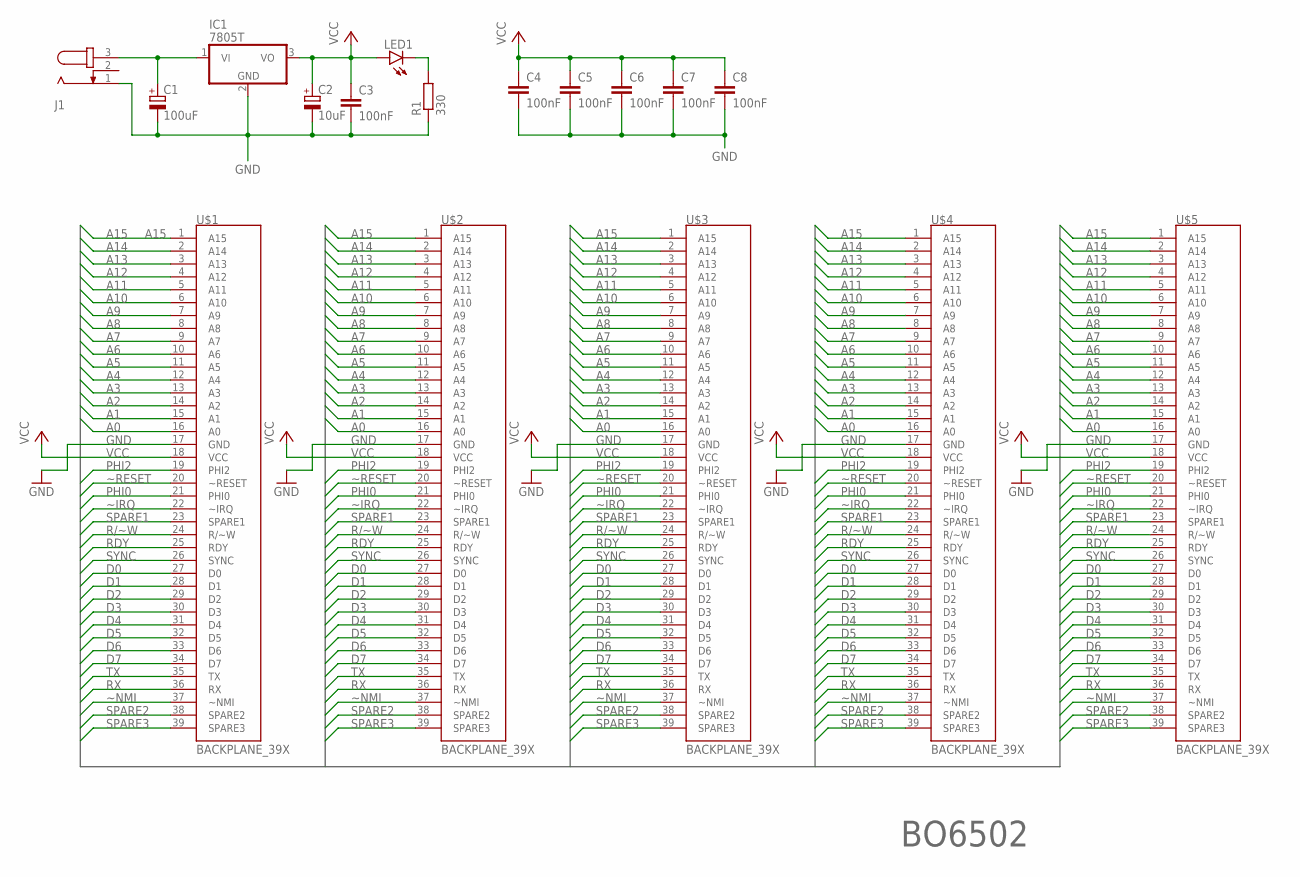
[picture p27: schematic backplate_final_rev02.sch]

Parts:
C1: 100uF; B45181A
C2: 10uF; B45181A
C3, C4, C5, C6, C7, C8: 100nF; C025-025X050
IC1: 7805T; TO220H
J1: JACK-PLUG1; SPC4078
LED1: LED5MM
R1: 330; 0207/10
U$1, U$2, U$3, U$4, U$5: BACKPLANE_39X; BP_39X

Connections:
A0: U$1.16 (A0), U$2.16 (A0), U$3.16 (A0), U$4.16 (A0), U$5.16 (A0)
A1: U$1.15 (A1), U$2.15 (A1), U$3.15 (A1), U$4.15 (A1), U$5.15 (A1)
A2: U$1.14 (A2), U$2.14 (A2), U$3.14 (A2), U$4.14 (A2), U$5.14 (A2)
A3: U$1.13 (A3), U$2.13 (A3), U$3.13 (A3), U$4.13 (A3), U$5.13 (A3)
A4: U$1.12 (A4), U$2.12 (A4), U$3.12 (A4), U$4.12 (A4), U$5.12 (A4)
A5: U$1.11 (A5), U$2.11 (A5), U$3.11 (A5), U$4.11 (A5), U$5.11 (A5)
A6: U$1.10 (A6), U$2.10 (A6), U$3.10 (A6), U$4.10 (A6), U$5.10 (A6)
A7: U$1.9 (A7), U$2.9 (A7), U$3.9 (A7), U$4.9 (A7), U$5.9 (A7)
A8: U$1.8 (A8), U$2.8 (A8), U$3.8 (A8), U$4.8 (A8), U$5.8 (A8)
A9: U$1.7 (A9), U$2.7 (A9), U$3.7 (A9), U$4.7 (A9), U$5.7 (A9)
A10: U$1.6 (A10), U$2.6 (A10), U$3.6 (A10), U$4.6 (A10), U$5.6 (A10)
A11: U$1.5 (A11), U$2.5 (A11), U$3.5 (A11), U$4.5 (A11), U$5.5 (A11)
A12: U$1.4 (A12), U$2.4 (A12), U$3.4 (A12), U$4.4 (A12), U$5.4 (A12)
A13: U$1.3 (A13), U$2.3 (A13), U$3.3 (A13), U$4.3 (A13), U$5.3 (A13)
A14: U$1.2 (A14), U$2.2 (A14), U$3.2 (A14), U$4.2 (A14), U$5.2 (A14)
A15: U$1.1 (A15), U$2.1 (A15), U$3.1 (A15), U$4.1 (A15), U$5.1 (A15)
D0: U$1.27 (D0), U$2.27 (D0), U$3.27 (D0), U$4.27 (D0), U$5.27 (D0)
D1: U$1.28 (D1), U$2.28 (D1), U$3.28 (D1), U$4.28 (D1), U$5.28 (D1)
D2: U$1.29 (D2), U$2.29 (D2), U$3.29 (D2), U$4.29 (D2), U$5.29 (D2)
D3: U$1.30 (D3), U$2.30 (D3), U$3.30 (D3), U$4.30 (D3), U$5.30 (D3)
D4: U$1.31 (D4), U$2.31 (D4), U$3.31 (D4), U$4.31 (D4), U$5.31 (D4)
D5: U$1.32 (D5), U$2.32 (D5), U$3.32 (D5), U$4.32 (D5), U$5.32 (D5)
D6: U$1.33 (D6), U$2.33 (D6), U$3.33 (D6), U$4.33 (D6), U$5.33 (D6)
D7: U$1.34 (D7), U$2.34 (D7), U$3.34 (D7), U$4.34 (D7), U$5.34 (D7)
GND: C1.-, C2.-, C3.2, C4.2, C5.2, C6.2, C7.2, C8.2, IC1.2 (GND), J1.1, R1.1, U$1.17 (GND), U$2.17 (GND), U$3.17 (GND), U$4.17 (GND), U$5.17 (GND)
unnamed: C1.+, IC1.1 (VI), J1.3
unnamed: LED1.K (C), R1.2
PHI0: U$1.21 (PHI0), U$2.21 (PHI0), U$3.21 (PHI0), U$4.21 (PHI0), U$5.21 (PHI0)
PHI2: U$1.19 (PHI2), U$2.19 (PHI2), U$3.19 (PHI2), U$4.19 (PHI2), U$5.19 (PHI2)
R/~W: U$1.24 (R/~W), U$2.24 (R/~W), U$3.24 (R/~W), U$4.24 (R/~W), U$5.24 (R/~W)
RDY: U$1.25 (RDY), U$2.25 (RDY), U$3.25 (RDY), U$4.25 (RDY), U$5.25 (RDY)
RX: U$1.36 (RX), U$2.36 (RX), U$3.36 (RX), U$4.36 (RX), U$5.36 (RX)
SPARE1: U$1.23 (SPARE1), U$2.23 (SPARE1), U$3.23 (SPARE1), U$4.23 (SPARE1), U$5.23 (SPARE1)
SPARE2: U$1.38 (SPARE2), U$2.38 (SPARE2), U$3.38 (SPARE2), U$4.38 (SPARE2), U$5.38 (SPARE2)
SPARE3: U$1.39 (SPARE3), U$2.39 (SPARE3), U$3.39 (SPARE3), U$4.39 (SPARE3), U$5.39 (SPARE3)
SYNC: U$1.26 (SYNC), U$2.26 (SYNC), U$3.26 (SYNC), U$4.26 (SYNC), U$5.26 (SYNC)
TX: U$1.35 (TX), U$2.35 (TX), U$3.35 (TX), U$4.35 (TX), U$5.35 (TX)
VCC: C2.+, C3.1, C4.1, C5.1, C6.1, C7.1, C8.1, IC1.3 (VO), LED1.A, U$1.18 (VCC), U$2.18 (VCC), U$3.18 (VCC), U$4.18 (VCC), U$5.18 (VCC)
~IRQ: U$1.22 (~IRQ), U$2.22 (~IRQ), U$3.22 (~IRQ), U$4.22 (~IRQ), U$5.22 (~IRQ)
~NMI: U$1.37 (~NMI), U$2.37 (~NMI), U$3.37 (~NMI), U$4.37 (~NMI), U$5.37 (~NMI)
~RESET: U$1.20 (~RESET), U$2.20 (~RESET), U$3.20 (~RESET), U$4.20 (~RESET), U$5.20 (~RESET)

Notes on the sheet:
BO6502

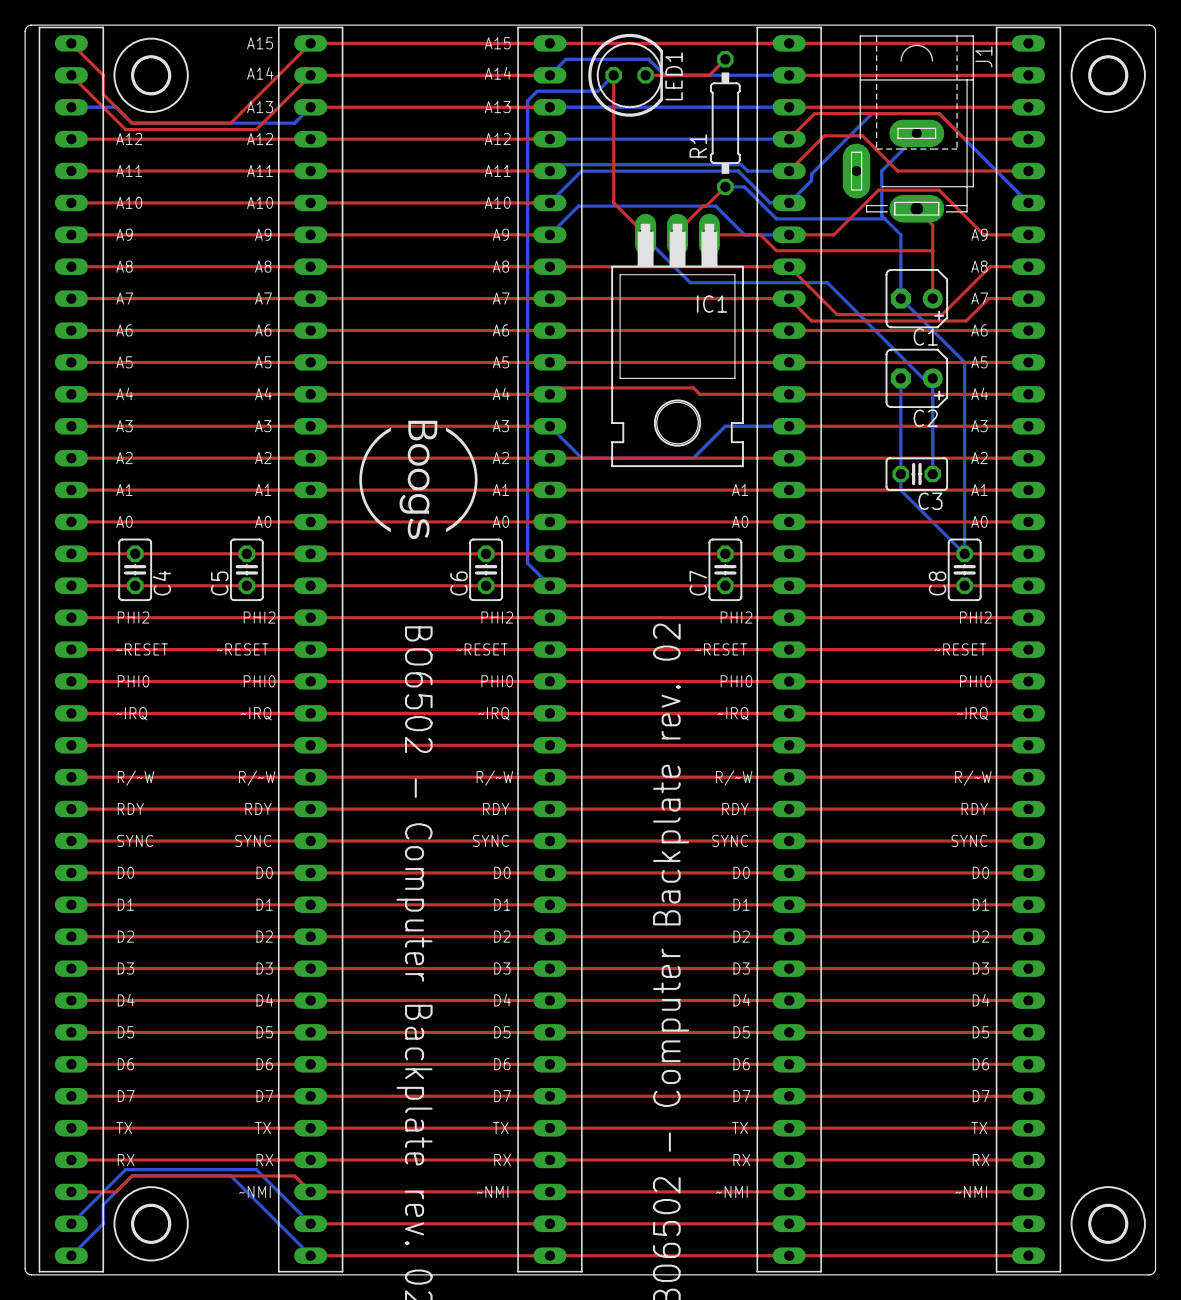
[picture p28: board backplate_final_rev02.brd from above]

Board: 2 copper layers, 90.0 x 99.5 mm, 21 parts (0 on the bottom side), 41 nets.

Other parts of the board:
U$7, U$8, U$9, U$10: 2,8

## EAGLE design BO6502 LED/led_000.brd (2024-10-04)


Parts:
C1, C2: 100n; C025-025X050
D1: SB140; DO41-10
IC2: 74AC138N; DIL16
LED1, LED2, LED3, LED4, LED5, LED6, LED7, LED8, LED9, LED10, LED11, LED12, LED13, LED14, LED15, LED16, LED17: RED; LED5MM
R1, R2, R3, R4, R5, R6, R7, R8, R9, R10, R11, R12, R13, R14, R15, R16, R17: 330; 0207/10
U1: 65C22; DIL40
U$1: BACKPLANE_39X; BP_39X

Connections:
A0: U1.38 (RS0), U$1.16 (A0)
A1: U1.37 (RS1), U$1.15 (A1)
A2: U1.36 (RS2), U$1.14 (A2)
A3: U1.35 (RS3), U$1.13 (A3)
A12: IC2.1 (A), U1.24 (CS1), U$1.4 (A12)
A13: IC2.2 (B), U$1.3 (A13)
A14: IC2.3 (C), U$1.2 (A14)
A15: IC2.6 (G1), U$1.1 (A15)
D0: U1.33 (D0), U$1.27 (D0)
D1: U1.32 (D1), U$1.28 (D1)
D2: U1.31 (D2), U$1.29 (D2)
D3: U1.30 (D3), U$1.30 (D3)
D4: U1.29 (D4), U$1.31 (D4)
D5: U1.28 (D5), U$1.32 (D5)
D6: U1.27 (D6), U$1.33 (D6)
D7: U1.26 (D7), U$1.34 (D7)
GND: C1.1, C2.1, IC2.4 (G2A), IC2.5 (G2B), IC2.8 (GND), LED1.K (C), LED2.K (C), LED3.K (C), LED4.K (C), LED5.K (C), LED6.K (C), LED7.K (C), LED8.K (C), LED9.K (C), LED10.K (C), LED11.K (C), LED12.K (C), LED13.K (C), LED14.K (C), LED15.K (C), LED16.K (C), LED17.K (C), U1.1 (GND), U$1.17 (GND)
unnamed: D1.C, U1.21 (~IRQ)
unnamed: LED2.A, R2.1
unnamed: LED3.A, R3.1
unnamed: LED1.A, R1.1
unnamed: LED4.A, R4.1
unnamed: LED5.A, R5.1
unnamed: LED6.A, R6.1
unnamed: LED7.A, R7.1
unnamed: LED8.A, R8.1
unnamed: LED9.A, R9.1
unnamed: LED10.A, R10.1
unnamed: LED11.A, R11.1
unnamed: LED12.A, R12.1
unnamed: LED13.A, R13.1
unnamed: LED14.A, R14.1
unnamed: LED15.A, R15.1
unnamed: LED16.A, R16.1
unnamed: LED17.A, R17.1
PA0: R9.2, U1.2 (PA0)
PA1: R8.2, U1.3 (PA1)
PA2: R7.2, U1.4 (PA2)
PA3: R6.2, U1.5 (PA3)
PA4: R5.2, U1.6 (PA4)
PA5: R4.2, U1.7 (PA5)
PA6: R3.2, U1.8 (PA6)
PA7: R2.2, U1.9 (PA7)
PB0: R17.2, U1.10 (PB0)
PB1: R16.2, U1.11 (PB1)
PB2: R15.2, U1.12 (PB2)
PB3: R14.2, U1.13 (PB3)
PB4: R13.2, U1.14 (PB4)
PB5: R12.2, U1.15 (PB5)
PB6: R11.2, U1.16 (PB6)
PB7: R10.2, U1.17 (PB7)
PHI0: U1.25 (PHI2), U$1.21 (PHI0)
R/~W: U1.22 (R/~W), U$1.24 (R/~W)
VCC: C1.2, C2.2, IC2.16 (VCC), R1.2, U1.20 (VCC), U$1.18 (VCC)
~CS2: IC2.10 (Y5), U1.23 (~CS2)
~IRQ: D1.A, U$1.22 (~IRQ)
~RESET: U1.34 (~RESET), U$1.20 (~RESET)

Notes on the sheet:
BO6502


Board: 2 copper layers, 101.3 x 65.0 mm, 40 parts (0 on the bottom side), 57 nets.

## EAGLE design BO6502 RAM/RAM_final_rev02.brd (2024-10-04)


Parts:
C1, C2, C3, C4, C5: 100n; C025-025X050
IC1: 74HCT00N; DIL14
IC2: 74AC138N; DIL16
IC3: HM62256; DIL28-6
IC4, IC5: 74HC08N; DIL14
J-CS0: J-CS0; JP2
J-CS1: J-CS1; JP2
J-CS2: J-CS2; JP2
J-CS3: J-CS3; JP2
J-CS4: J-CS4; JP2
J-CS5: J-CS5; JP2
J-CS6: J-CS6; JP2
J-CS7: J-CS7; JP2
JP1: JP1
JP2: JP2; JP1
JP3: JP3; JP2
JP4: JP4; JP2
LED1: RED; LED5MM
R1: 330; 0207/10
U$1: BACKPLANE_39X; BP_39X

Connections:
A0: IC3.10 (A0), U$1.16 (A0)
A1: IC3.9 (A1), U$1.15 (A1)
A2: IC3.8 (A2), U$1.14 (A2)
A3: IC3.7 (A3), U$1.13 (A3)
A4: IC3.6 (A4), U$1.12 (A4)
A5: IC3.5 (A5), U$1.11 (A5)
A6: IC3.4 (A6), U$1.10 (A6)
A7: IC3.3 (A7), U$1.9 (A7)
A8: IC3.25 (A8), U$1.8 (A8)
A9: IC3.24 (A9), U$1.7 (A9)
A10: IC3.21 (A10), U$1.6 (A10)
A11: IC3.23 (A11), U$1.5 (A11)
A12: IC2.1 (A), IC3.2 (A12), U$1.4 (A12)
A13: IC2.2 (B), JP1.2, U$1.3 (A13)
A14: IC2.3 (C), JP2.2, U$1.2 (A14)
A15: IC1.1 (I0), IC1.2 (I1), JP3.1, U$1.1 (A15)
CS: IC3.20 (!CS), IC5.8 (O)
CS0: IC2.15 (Y0), J-CS0.3
CS1: IC2.14 (Y1), J-CS1.3
CS2: IC2.13 (Y2), J-CS2.3
CS3: IC2.12 (Y3), J-CS3.3
CS4: IC2.11 (Y4), J-CS4.3
CS5: IC2.10 (Y5), J-CS5.3
CS6: IC2.9 (Y6), J-CS6.3
CS7: IC2.7 (Y7), J-CS7.3
D0: IC3.11 (I/O0), U$1.27 (D0)
D1: IC3.12 (I/O1), U$1.28 (D1)
D2: IC3.13 (I/O2), U$1.29 (D2)
D3: IC3.15 (I/O3), U$1.30 (D3)
D4: IC3.16 (I/O4), U$1.31 (D4)
D5: IC3.17 (I/O5), U$1.32 (D5)
D6: IC3.18 (I/O6), U$1.33 (D6)
D7: IC3.19 (I/O7), U$1.34 (D7)
EN: IC2.6 (G1), JP3.2
GND: C1.1, C2.1, C3.1, C4.1, C5.1, IC1.7 (GND), IC2.4 (G2A), IC2.5 (G2B), IC2.8 (GND), IC3.14 (VSS), IC4.7 (GND), IC5.7 (GND), IC5.12 (I0), IC5.13 (I1), LED1.K (C), U$1.17 (GND)
unnamed: IC3.26 (A13), JP1.1
unnamed: IC1.5 (I1), IC1.11 (O)
unnamed: IC1.3 (O), JP3.3
unnamed: IC1.6 (O), JP4.3
unnamed: IC4.3 (O), IC5.1 (I0)
unnamed: LED1.A, R1.1
unnamed: IC4.6 (O), IC5.2 (I1)
unnamed: IC4.8 (O), IC5.4 (I0)
unnamed: IC3.1 (A14), JP2.1
unnamed: IC4.11 (O), IC5.5 (I1)
unnamed: IC5.3 (O), IC5.9 (I0)
unnamed: IC5.6 (O), IC5.10 (I1)
unnamed: IC4.1 (I0), J-CS0.2
unnamed: IC4.2 (I1), J-CS1.2
unnamed: IC4.4 (I0), J-CS2.2
unnamed: IC4.5 (I1), J-CS3.2
unnamed: IC4.9 (I0), J-CS4.2
unnamed: IC4.10 (I1), J-CS5.2
unnamed: IC4.12 (I0), J-CS6.2
unnamed: IC4.13 (I1), J-CS7.2
OE: IC1.8 (O), IC3.22 (!OE)
PHI0: IC1.4 (I0), IC1.10 (I1), U$1.21 (PHI0)
R/~W: IC1.9 (I0), IC1.12 (I0), IC1.13 (I1), U$1.24 (R/~W)
VCC: C1.2, C2.2, C3.2, C4.2, C5.2, IC1.14 (VCC), IC2.16 (VCC), IC3.28 (VCC), IC4.14 (VCC), IC5.14 (VCC), J-CS0.1, J-CS1.1, J-CS2.1, J-CS3.1, J-CS4.1, J-CS5.1, J-CS6.1, J-CS7.1, JP4.1, R1.2, U$1.18 (VCC)
WE: IC3.27 (!WE), JP4.2

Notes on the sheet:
BO6502


Board: 2 copper layers, 101.6 x 65.0 mm, 25 parts (0 on the bottom side), 60 nets.

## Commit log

2024-10-04 Adding RAM
    [RAM_final_rev02.brd, RAM_final_rev02.sch]
2024-10-05 R3 wrong value
    [LCD_KEYb_final_rev02.brd, LCD_KEYb_final_rev02.sch]

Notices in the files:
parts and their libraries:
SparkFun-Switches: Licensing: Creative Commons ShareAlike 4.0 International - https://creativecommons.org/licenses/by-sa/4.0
